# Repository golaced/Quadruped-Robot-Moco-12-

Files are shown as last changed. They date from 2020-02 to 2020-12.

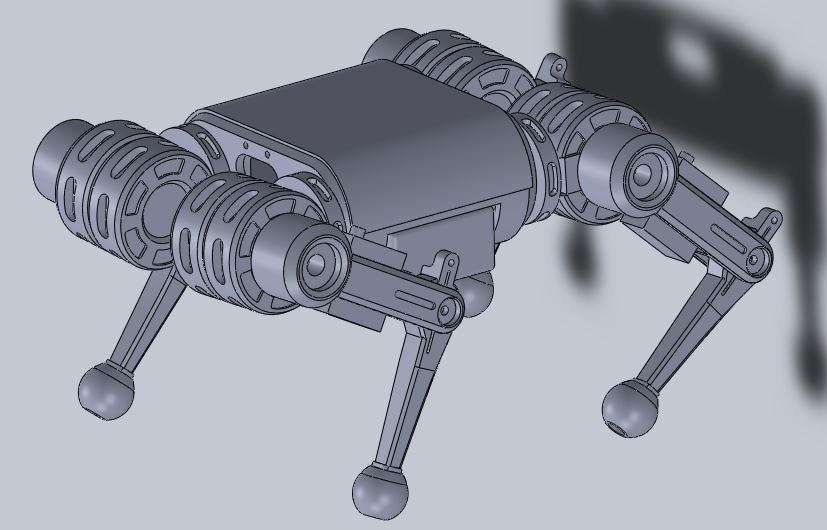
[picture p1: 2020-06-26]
教程2-主机架设计/moco-8 Test Verison/设计图/5.JPG

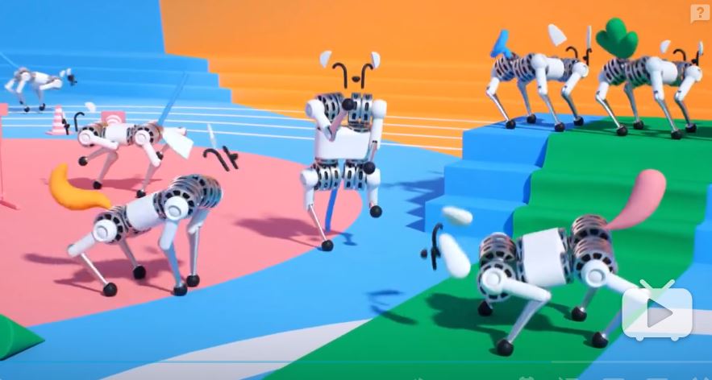
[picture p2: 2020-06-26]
教程2-主机架设计/moco-8 Test Verison/设计图/3.JPG

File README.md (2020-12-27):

# 1 Moco通用四足机器人控制器介绍  


  ____MOCO通用机器人控制器是一个面向四足、双足、六足与无人机通用的嵌入式控制器，其设计的理念是最大程度降低机器人爱好者软件开发的工作，借鉴乐高MOC构建的理念提供高性能、易用、多兼容、可快速定制的机器人/模型控制器。MOCO通用机器人控制器本质上并非一个开源飞控或机器人控制器，为提高高性能的控制效果，不同构型的机器人均采用了很多原创的算法并经过很长时间的改进，所以为保护知识产权抱歉无法为用户提供完全开源的软件代码，你可以理解为这个控制器和DJI早期NAZA飞控一样不具有完全的底层代码开发性但是配套了针对特定机器人构型所需易用的上位机能让用户快速地完成参数配置与驱动器标定，同时我们也提供丰富的二次开发接口从顶层的机器人本体位姿期望到底层的驱动器输出和关节角度均可以通过通讯协议设置，为电子开发爱好者提供一个桌面级的机器人底盘实现SLAM、人工智能和机器人视觉的开发。当然你如果对开发不感兴趣在安装完成后控制器已经能完成出色到的控制效果，你只需要关注结果设计与涂装专注于缩比模型的构建，当然它是具有高性能可动的缩比模型！<br><br>

**相关资料** <br>
机器人测试视频更新地址：https://www.bilibili.com/video/BV1Bi4y1w71m <br>
知乎相关教程：https://www.zhihu.com/column/c_1090923972006240256<br>
<br>

**-搭建该项目的方式-**

方式|说明|发货周期
-------------|-------------|-------------
整机购买(**推荐**)|从官方淘宝店购买机架+已经加工好的控制器(不包含舵机)|最长半个月
机架打印+控制器购买|自行加工项目文件免费提供的3D打印机架 +从官方购买控制器+自己购买舵机|最长1周
机架打印+控制器制版加工|自行加工3D打印机架+自行制作、焊接控制器+自己购买舵机|控制器(4层板)+IMU+下载器转接+供电模块
<br>
官方淘宝店（莲动力）：https://item.taobao.com/item.htm?spm=a1z10.1-c-s.w4004-23351273156.30.138111fbf8R4Qv&id=624417919694
<br>
<br>
**-舵机兼容-**

舵机|说明|价格
-------------|-------------|-------------
GDW9g舵机|可支持软断点|138Rmb
飞特9g总线舵机|总线控制|39Rmb
自定义|上位机配置参数| 

<br>
**-开源程序与VMC机器人库-**

方式|说明|开源模式
-------------|-------------|-------------
(**VMC机器人库**)|支持多种着地反馈、动态步态调节和更稳定的姿态控制能力，需要向官方购买授权码|闭源(目前支持STM32F4系列，且库与芯片ID绑定)
开源程序|支持基础对角步态和姿态控制|开源

<br>
**-二次开发接口-**

方式|说明|接口
-------------|-------------|-------------
Python|支持底盘、运动学等多种API|需使用USB与主控连接
C|采用串口以底盘模式提供API|树莓派等串口连接 https://github.com/golaced/MOCO_SDK
ROS|采用串口以底盘模式提供API，ROS下图像识别节点|树莓派等串口连接 https://github.com/golaced/MOCO_SDK

<br>
**-如果该项目对您有帮助请 Star 我们的项目-**<br>
**-如果您愿意分享对该项目的优化和改进请联系golaced@163.com或加入我们的QQ群567423074，加速开源项目的进度-**<br>

<br>
**-由于本人非专业研究四足机器人，该项目只是基于个人学术水平开发并不代表目前足式机器人算法就是这样，请不要过分依赖项目内容或与正规产品对比-**<br>
	
# 2 Moco-12四足机器人平台介绍

____MOCO-12 Pro是一个12自由度舵机缩比机器人模型，其原型来自于伊利诺伊大学厄巴纳大学丁博士的电驱动四足机器人，该机器人造型帅气而且体积十分小可以完全作为桌面级的机器人平台，单腿电机设计也采用了类似MIT那种三关节+连杆集成在跨关节的方式，整体机械结构的集成度十分高，原始机器人采用了MPC控制算法可以说是与MIT机器人能相媲美的一个四足机器人，我们提供的缩比模型在整体结构上较好地模仿了原型结构设计，采用连杆作为主机架，考虑舵机执行器安装对部分结构进行了修改。<br><br>

**控制器硬件参数：**

项目|参数
-------------|-------------
处理器|STM32F405RGT6
处理器性能|32Bit ARM Cortex-M4 168MH
陀螺仪 加速度计|LSM6DS33 
磁力计|LIS3MDL
气压计|MS5611
预留接口|GPS-1 串口-4 AD采样-4 着地开关输入-4
PWM 输出通道| 12通道输出 
供电|5V输入 舵机外部供电  AD传感器3.3/5V供电选择
图像处理器|树莓派A3+  1.4G 4核  带独立供电开关(控制板兼容树莓派全系列可作为外扩IO板安装，但通讯仅采用引脚串口)
遥控方式|2.4G射频 SBUS航模遥控
地面站|QGround   匿名地面站(需要额外OLDX-REMOTE监视器)

**机器人参数：**

项目|参数
-------------|-------------
足式机器人类型|8自由度并联机器人
尺寸|30cm * 20cm *10cm  
全腿长|8cm
重量|600g
供电|7.4V  18650 * 2(3000mah  续航>35 min) 带开关 
步态支持|Tort步态  Fly-Trot步态  波动步态
最大移动速度|0.4m/s
最大转向速度|30度/s
步态周期|>0.35 s
舵机性能|Kpower 12g金属舵机 *8(6V-60度/0.035s  9kg扭矩)
足底传感器|薄膜压力/微动开关(默认无传感器)
控制模式|遥控模式  姿态平衡模式(有/无着地传感器)  驾驶模式  

# 3 捐赠与项目后续开发计划
____团队计划后期推出5kg~10kg级的足式机器人开发底盘，支持RPlidar激光雷达导航进行SLAM算法验证，能以相同的价格替代目前市面上同类的四轮小车平台如Autolabor等。
 
____如果您觉得该项目对您有帮助，也为了更好的项目推进和软硬件更新，如果愿意请通过微信捐赠该项目！


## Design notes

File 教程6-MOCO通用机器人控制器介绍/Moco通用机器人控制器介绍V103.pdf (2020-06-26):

文档版本 Ver 1.04 | 修正日期 2020/6/25

# MOCO 通用机器人控制器帮助文档

# 一、MOCO 通用机器人控制器

## 1. 简介

MOCO 通用机器人控制器是一个面向四足、双足、六足与无人机通用的嵌入

式控制器，其设计的理念是最大程度降低机器人爱好者软件开发的工作，借鉴乐

高 MOC 构建的理念提供高性能、易用、多兼容、可快速定制的机器人/模型控制

器。MOCO 通用机器人控制器本质上并非一个开源飞控或机器人控制器，为提高

高性能的控制效果，不同构型的机器人均采用了很多原创的算法并经过很长时间

的改进，所以为保护知识产权抱歉无法为用户提供完全开源的软件代码，你可以

理解为这个控制器和 DJI 早期 NAZA 飞控一样不具有完全的底层代码开发性但是

配套了针对特定机器人构型所需易用的上位机能让用户快速地完成参数配置与

驱动器标定，同时我们也提供丰富的二次开发接口从顶层的机器人本体位姿期望

到底层的驱动器输出和关节角度均可以通过通讯协议设置，为电子开发爱好者提

供一个桌面级的机器人底盘实现 SLAM、人工智能和机器人视觉的开发。当然你

如果对开发不感兴趣在安装完成后控制器已经能完成出色到的控制效果，你只需

要关注结果设计与涂装专注于缩比模型的构建，当然它是具有高性能可动的缩比

模型！

## 2. 控制器硬件资源

MOCO 控制器采用 STM32 单片机作为 CPU 板载基本的陀螺仪与加速度计，

预留 12 路 PWM 输出与 4 路模拟量和开关输入，外部信号输入预留一路 SBUS 接

收机和 2 路串口，板载 5V DCDC 各 PWM 引脚供电采用外部电池输入同时具有 1

路电源使能信号输出，预留一路 USB 调试接口实现与上位机高速通讯，控制器

主板如下图所示。

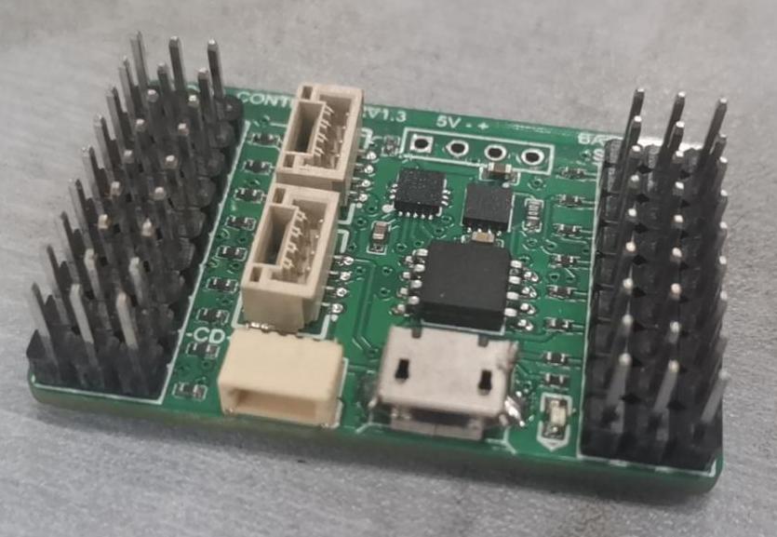
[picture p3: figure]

图 1 MOCO 通用机器人控制器（USB 端子版本）

主控尺寸小于 5*3cm 能集成到桌面级的机器人系统中，控制器各硬件资源如

下表所示：

表 1 MOCO 通用机器人硬件资源

项目 | 性能 | 备注
STM32F405RGT | 168Mhz 1K Flash | 主控芯片
LSM6DS33 | 加速度计+陀螺仪 | 6 轴姿态传感器
W25X16 | 16M-bits Flash | 参数存储芯片
AS1364-BTDT-33 | 3.3V 稳压 | 单片机降压
PWM 接口数量 | 12 个 | 外部供电
串口 | 2 路 | Uart1 Uart4
USB | 1 路 | OCU 通讯
SWD | 1 路 | 5V 供电
模拟/开关输入 | 4 路 | 3.3V 逻辑 5V 供电
SBUS | 1 路 | 5V 供电
LED | 2 个 | 状态显示
电源输入范围 | 6~20V | 5V 内部降压

连接上位机可以通过主控制器 UART1 口或者 USB 口，USB 口需要转接板，注

意！！！对于 USB 端子为卧贴的主控 4P 软线需要连接转接板的 B 面：

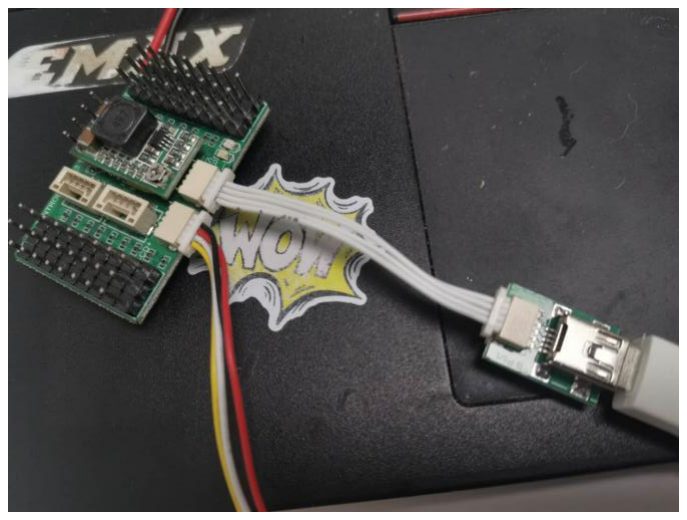
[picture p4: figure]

## 3. 控制器引脚分配

目前单片机引脚已经完全分配，后续扩展模块通过串口内部高速通讯，目前

预留的串口主要用于远程 OCU 连接、SDK 输入与遥控输入（UART1），扩展定位

模块、驱动器节点盒与传感器（UART4），单片机引脚分配如下表所示：

表 2 控制器硬件引脚分配

引脚 | 功能 | 备注
PA1 | ADC1_1 | 电池电压采集
PA4-7 | ADC1_4-7 | AD/开关量采集
PA8 | TIM1_1 | PWM9
PA9 | UART1_TX | 串口 1 发送
PA10 | UART1_RX | 串口 1 接收
PA11 | DM | USB- PA12 | DP | USB+
PA13 | SWD | 下载器
PA14 | SCK | 下载器
PB0 | TIM3_3 | PWM3
PB1 | TIM3_4 | PWM4
PB4 | TIM3_1 | PWM1
PB5 | TIM3_2 | PWM2
PB6 | TIM4_1 | PWM5

PB7 | TIM4_2 | PWM6
PB10 | TIM2_3 | PWM7
PB11 | TIM2_4 | PWM8
PB12 | | LED_R
PB13 | SPI2_SCK
PB14 | SPI2_SO
PB15 | SPI2_SI
PC0 | | LED_G
PC4 | | SPI2_IMU 片选
PC5 | | SPI2_FLASH 片选
PC6 | TIM8_1 | PWM10
PC7 | TIM8_2 | PWM11
PC8 | TIM8_3 | PWM12
PC9 | | 电源开关信号 3.3V
PC10 | UART4_TX | 串口 4 发送
PC11 | UART4_RX | 串口 4 接收
PD2 | UART5_RX | 反向/SBUS 接收

## 4. 控制器端子说明

主控端子均朝向上方采用典型飞控的引脚分配使用 2.54 排针作为主伺服控

制信号的输出，SWD 与 USB 均采用 1.25 端子引出方便不调试时去除连线，USB

调试口配套对应连接转换板方便控制器内置时的参数调节，动力主供电通过 PCB

右上角焊盘或供电线引出，主控控制电通过 PWM 排针输入同时输出 1 路开关信

号给外部继电器或电源控制器实现对动力电的关闭和开启，4 路模拟量/开关信

号输入能作为四足机器人足底传感器或开关传感器的输入，SBUS 接受引脚实现

对航模遥控器信号的采集，具体端子分布如下图所示。

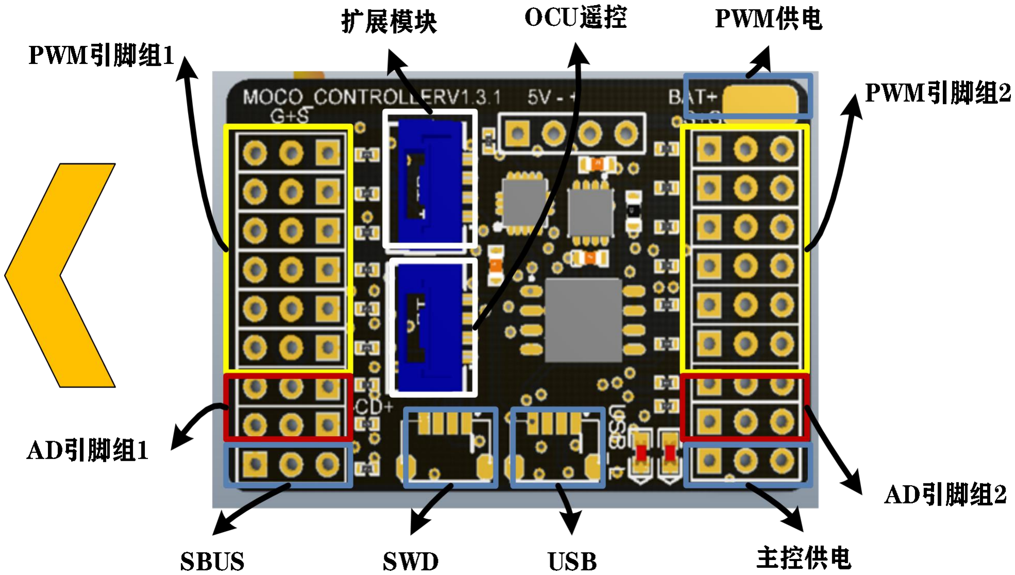
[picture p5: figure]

图 2 控制器端子示意图（《箭头为机头方向）

如上图所示，PWM 供电焊盘上面为 VCC+背面为 GND（最大输入 24V）LF 左

前，RF 右前，LH 左后，RH 右后。

PWM 引脚组 1 一侧对应的引脚说明如下：

从上到下 | 功能 | | 从左到右
PWM6 | RF 腿小腿 | GND | VBAT | Signal
PWM5 | RF 腿大腿 | GND | VBAT | Signal
PWM2 | RF 腿侧摆 | GND | VBAT | Signal
PWM1 | LF 腿侧摆 | GND | VBAT | Signal
PWM11 | LF 腿大腿 | GND | VBAT | Signal
PWM12 | LF 腿小腿 | GND | VBAT | Signal
GROUND2 | RF 腿足底采集 | GND | 5V | Signal
GROUND1 | LF 腿足底采集 | GND | 5V | Signal
SBUS | 遥控输入 | GND | 5V | Signal

如上图所示，PWM 引脚组 2 一侧对应的引脚说明如下：

从上到下 | 功能 | | 从左到右
PWM3 | RH 腿小腿 | Signal | VBAT | GND
PWM4 | RH 腿大腿 | Signal | VBAT | GND

PWM7 | RH 腿侧摆 | Signal | VBAT | GND
PWM8 | LH 腿侧摆 | Signal | VBAT | GND
PWM10 | LH 腿大腿 | Signal | VBAT | GND
PWM9 | LH 腿小腿 | Signal | VBAT | GND
GROUND3 | RH 腿足底采集 | Signal | 5V | GND
GROUND4 | LH 腿足底采集 | Signal | 5V | GND
POWER | 控制电输入 | 电源开关 | VBAT | GND

如上图所示，SWD 引脚组对应的说明如下：

功能 | 从左到右
SWD | GND | SCK | SWD | 5V

如上图所示，USB 引脚组对应的说明如下：

功能 | 从左到右
USB | 5V | DM | DP | GND

如上图所示，扩展模块引脚组对应的说明如下：

功能 | 从上到下
UART4 | RX
| TX
| GND
| 5V

如上图所示，OCU 遥控引脚组对应的说明如下：

功能 | 从上到下
UART1 | TX
| RX
| GND
| 5V

## 5. 控制器使用电气连接

控制器电气连接主要完成 PWM 与舵机或无刷电机驱动器的连接，PWM 供电

线与电池的连接，主控供电线与电池的连接，遥控器的连接，USB 与上位机的连

接，外扩模块与串口的连接，则具体连线示意图如下所示。

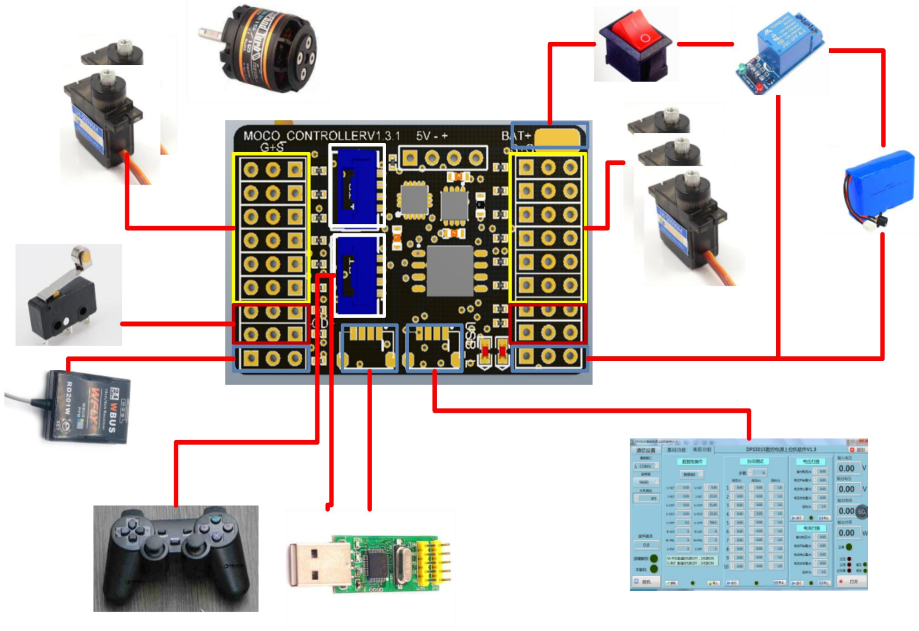
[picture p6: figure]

图 3 控制器电气连接

如上图所示，PWM 接口可以直接连接舵机驱动或者连接电子调速器驱动无

刷电机，AD 接口可以连接微动开关采集足底开关信息，OCU 端子可以选择连接

无线遥控器接收器或者直接连接 SWD/TTL 转串口一体模块，USB 端口则连接

OCU，上述遥控输入 SBUS 优先级高于串口、串口高于 OCU。供电端电池同时给

板子 DCDC 与 PWM 引脚供电，供电口输出的开关信号可以用于控制继电器开关

动力电源，同时也可以增加一个主动开关。

注意：控制器默认 PWM 供电与控制电是分开的，所有到手直接连接 PWM

的 JST 供电口控制器是不会上电的，因此需要从外部引入一路电池到供电引脚

（注意千万不要插错），或者直接从主控 PWM 供电+极焊盘引出一路电源到主

控供电引脚！！！！！

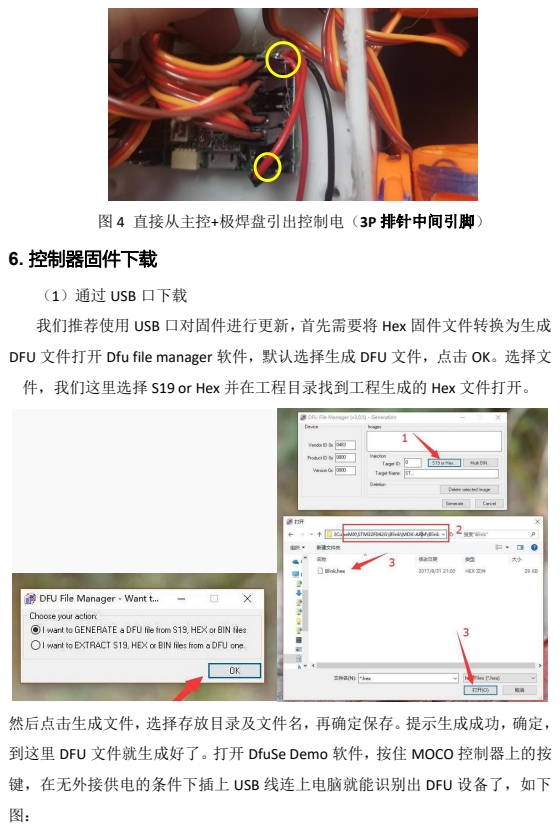
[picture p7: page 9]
6. 控制器固件下载

图 4 直接从主控+极焊盘引出控制电（3P 排针中间引脚）

（1）通过 USB 口下载

我们推荐使用 USB 口对固件进行更新，首先需要将 Hex 固件文件转换为生成
DFU 文件打开 Dfu file manager 软件，默认选择生成 DFU 文件，点击 OK。选择文

件，我们这里选择 S19 or Hex 并在工程目录找到工程生成的 Hex 文件打开。

然后点击生成文件，选择存放目录及文件名，再确定保存。提示生成成功，确定，
到这里 DFU 文件就生成好了。打开 DfuSe Demo 软件，按住 MOCO 控制器上的按

键，在无外接供电的条件下插上 USB 线连上电脑就能识别出 DFU 设备了，如下

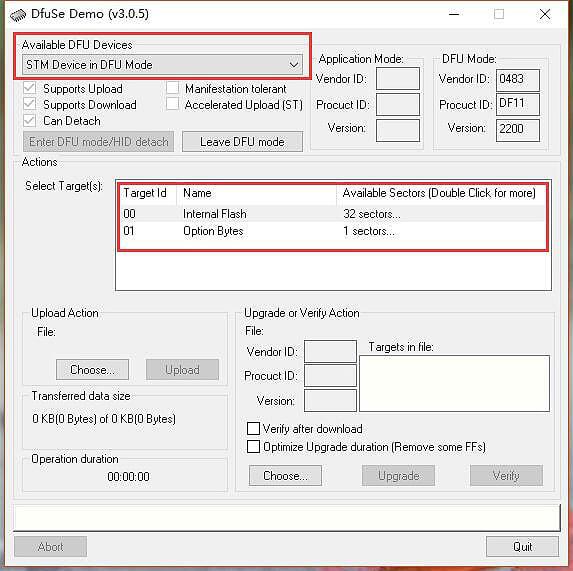
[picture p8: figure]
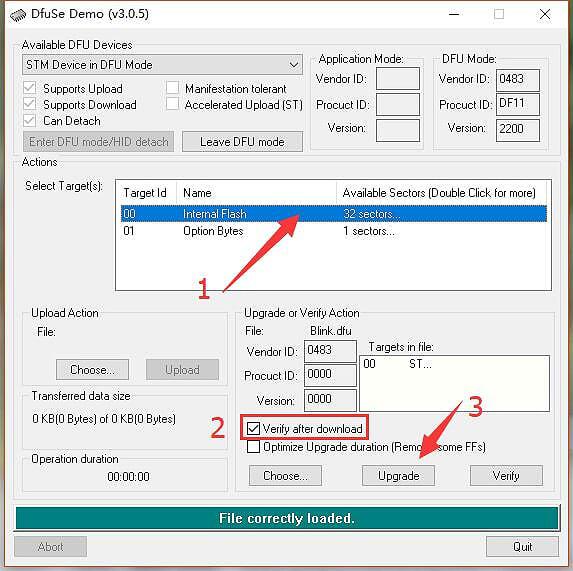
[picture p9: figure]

选择文件，在弹出窗口中找到之前软件生成的 DFU 文件或者下载的 DFU 文件，

## 选择并打开。双击 Target Id 中的 STM32 Flash 一栏，点击 Choose 选择刚才生成

到的 Dfu 文件后，点击 Upgrade 进行下载，当读条完毕无错误报出则可以连接

OCU 上位机查看固件版本。

（2）通过 SWD 口下载

目前控制器固件需要通过 STlink 下载，首先使用转接线与 STlink 的 SWD 接口

对接并从下载口提供 5V 供电，之后使用 STM32 ST-LINK Utility 下载固件。首先

连接单片机 ，正确连接后显示：

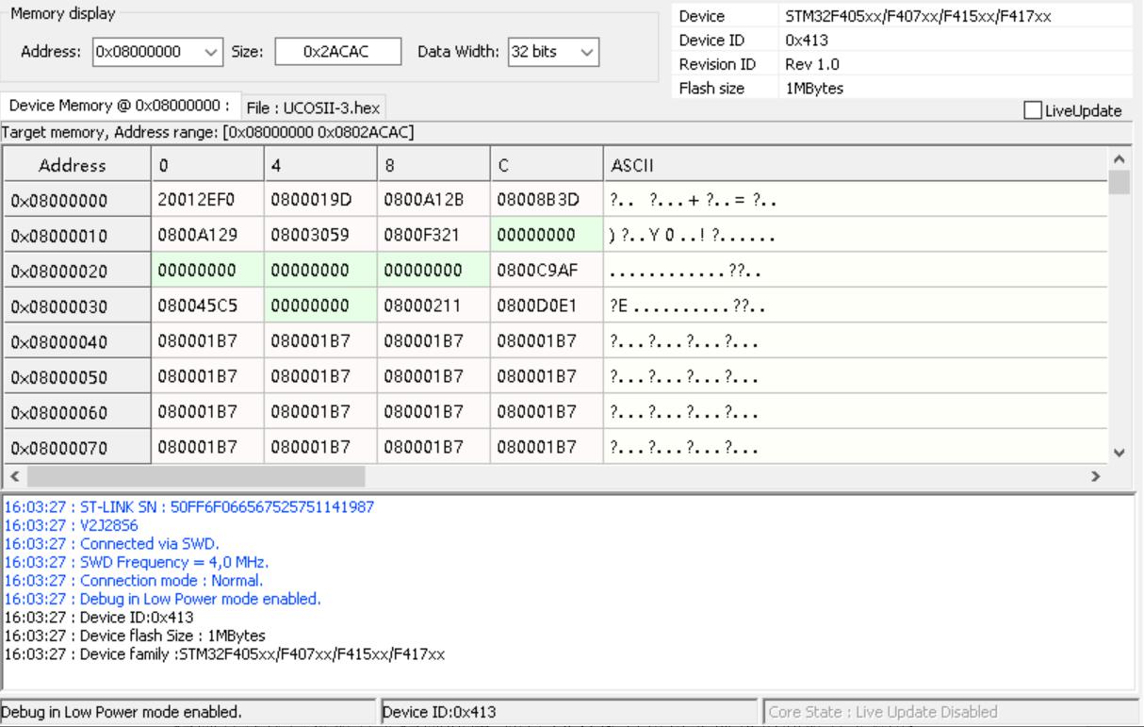
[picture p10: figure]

之后选择需要下载的固件，点击 File 选择 Open File 功能，找到 Moco.hex 固件确

认：

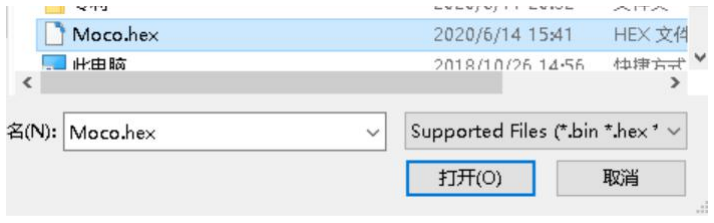
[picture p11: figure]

## 选择 Target 点击 Program and Vertify 下载固件：

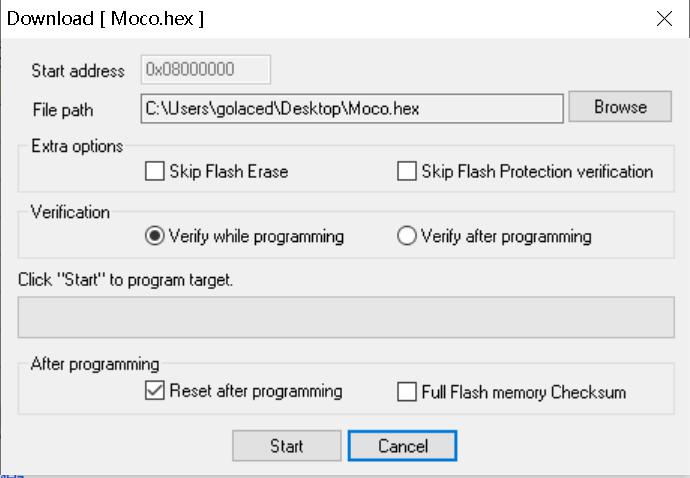
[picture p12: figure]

点击 Start 开始下载当读条完毕，并显示如下说明则固件下载完成：

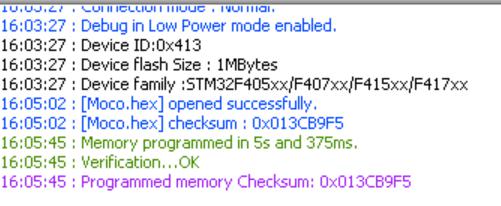
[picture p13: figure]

（3）V1.3 硬件版本 USB 固件下载示意

在 V1.3 版本硬件中没用增加 Boot 引脚上拉接口，因此可能无法直接使用 USB

下载固件，为方便后续调试我们推荐有能力的开发者自行在电路板对应电阻焊接

一个杜邦线方便上拉下载固件：

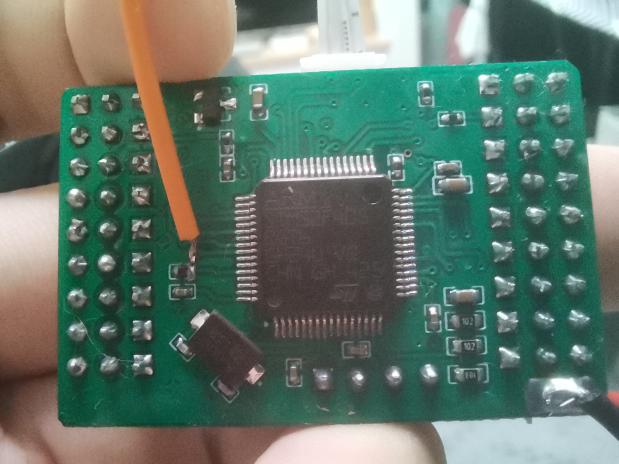
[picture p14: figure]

如上图所示用户需要在控制器背面晶振上方电阻的内测焊盘点上一根杜邦

线，注意不要焊接错误！！

则当需要烧写固件时将其插在排针输出中任意 5V 输出位置，注意不要插在

12 路 PWM 的供电引脚因为其为电池电压高于 5V，我们推荐插在下图位置并且

下载固件时只使用 USB 供电：

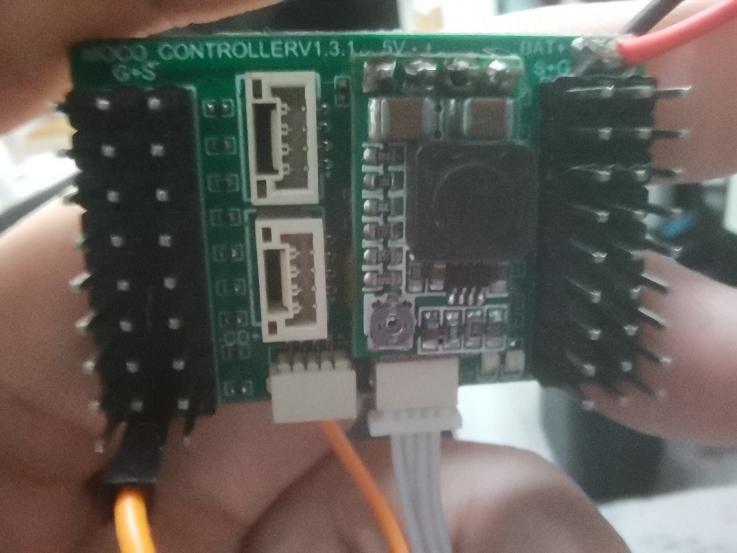
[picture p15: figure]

则当连接正确后将 USB 与转接模块连接，注意电路板 USB 4P 端子与目前转

接板的 B 面连接：

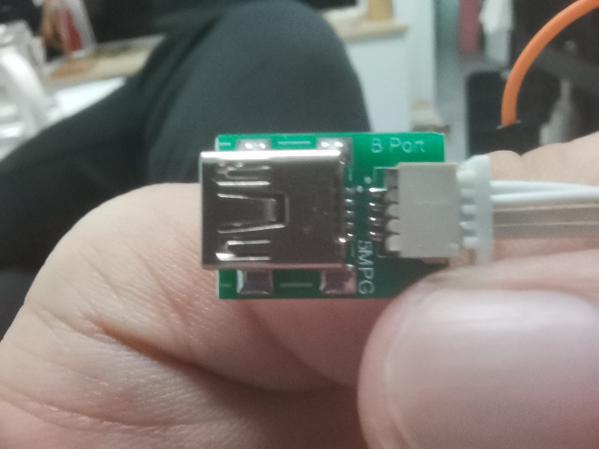
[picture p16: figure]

## 7. 控制器使用与授权

控制器默认烧录机器人控制固件，通过 OCU 配置可以完成对不同机器人构型

的选择和参数的调节，另外用户也可以自己通过 SWD 烧录程序将其作为一个

STM32F4 单片机开发板使用，为保护自主知识产权控制器仍然采用 OLDX 飞控软

件授权的方式，即 MOCO 机器人控制固件仅与官方加工的硬件绑定的方式实现，

用户使用软件需要提供 OCU 上显示的芯片 ID 并获取授权码（在上位机参数界面

写入并保存）。

当然我们也提供面向任意同系列单片机和开发板的通用固件，其相关步态功

能和机器人参数会受到限制，具体说明请查看《上位机帮助使用说明文档》。

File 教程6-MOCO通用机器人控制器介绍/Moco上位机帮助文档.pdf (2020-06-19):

文档版本 Ver 1.0 | 修正日期 2020/6/1

# MOCO 通用机器人 OCU 帮助文档

# 一、MOCO 通用 OCU 上位机

## 1. 简介

MOCO 通用 OCU 上位机是支持 MOCO 机器人控制器进行快速配置与参数调

节的跨平台软件，其基于 Python 内核能部署于 Windows 与 Ubuntu 系统。上位

机支持对机器人构型的选择可以快速完成 MOCO 系列四足机器人的建立，同时

还支持用户基于机器人构型参数快速自定义，同时上位机集成参数在线调节功能

能快速实现参数的整定并配有波形显示为姿态控制参数整定提供可视化指标。为

方便用户测试上位机提供了对舵机输出的标定界面用户能快速完成角度偏差标

定与转向标定，同时提供完善的测试步骤在机器人标定配置完成后用户依据测试

流程既可以完成对机器人稳定性的快速调试，为实现参数保存上位机也支持对配

置参数的本地存储与快速写入，相比上一代代码调节的方式大大加快机器人的调

试！

备注：环境配置，将“MOCO_OCU 图片”文件夹复制到 D:/根目录下

## 2. OCU 上位机功能介绍

OCU 上位机主要分为主界面、机器人向导、参数设置、执行器标定、传感器

标定、测试模式与控制模式几大界面，连接上位机可以通过主控制器 UART1 口

或者 USB 口，USB 口需要转接板，注意！！！对于 USB 端子为卧贴的主控 4P 软线

需要连接转接板的 B 面：


各界面主要功能如下：

（1）主界面：

该界面主要完成机器人状态的显示，包括姿态、位置、速度、控制模式等，

同时以图像的模式显示各关键角度，同时可以在主界面完成串口配置以及对波形

曲线的查看。

（2）机器人向导：

该界面主要完成对机器人快速的向导式配置，可以选择 Moco 系列机器人实

现对官方特定构型机器人参数的配置和下载，另外也可以通过 DIY 模式依据用户

自己的机器人参数进行设置。

（3）参数配置界面：

该界面主要对机器人内部参数的在线整定和保存，可以完成对机器人典型位

姿控制增益，落足、姿态偏差的调节，也可以实现对参数的快速恢复出厂设置。

（3）执行器标定界面：

该界面主要完成对 12 路 PWM 输出的快速标定，包括各 PWM 输出的偏差以

及执行器旋转的方向，同时也可以完成对舵机时间参数的标定让用户使用自己的

舵机数据。

（4）传感器标定界面：

该界面主要完成对板载 IMU 的标定包括对其测量偏差和尺度偏差，对磁场的

在线拟合标定以及 GPS 和 IMU 安装位置角度的标定。

（5）测试模式界面：

该界面主要完成在机器人配置完成后对各独立功能的快速测试来验证参数

配置的正确性，包括正逆运动学、伪逆力控和位姿调节等。

（6）控制模式界面：

该界面主要为用户提供一个在无遥控器下快速测试机器人的方法，可以实际

基于按键与键盘操作下机器人速度、姿态和步态的快速调节。

## 3. 状态主界面介绍

该界面主要完成机器人状态的显示，包括姿态、位置、速度、控制模式等，

同时以图像的模式显示各关键角度，同时可以在主界面完成串口配置以及对波形

曲线的查看，具体功能如下：

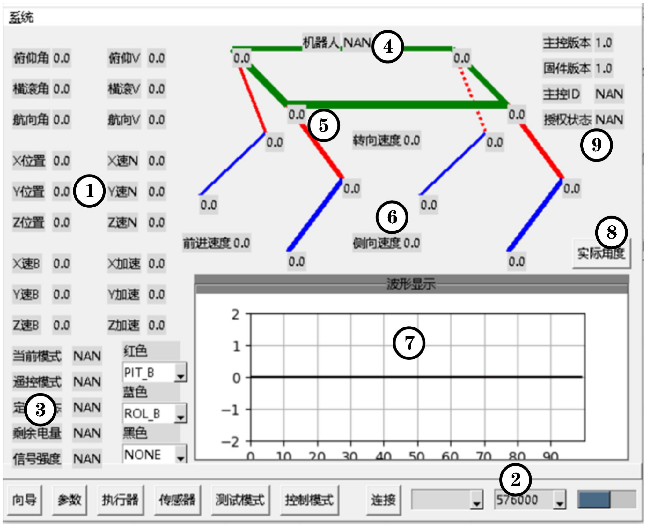
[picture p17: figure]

图 1 状态主界面

上图中各标号对应功能如下：

①机器人状态显示栏：完成对机器人姿态角、角速度、加速度、位置、速度

的显示；

②串口设置：系统连接后默认搜索串口，也可以点击下拉栏选择 COM 口和

波特率，当串口连接后右侧数据条会不断走动，如串口通信故障请查看控制台打

印信息并查看后文故障处理说明章节；

③模式显示栏：完成对机器人状态的显示，其中当前模式显示机器人步态状

态如下:

状态 | 遥控切换操作 | 功能
离线 | 无 | 机器人未连接 OCU
安全 | 遥控下 | 关闭动力电源
站立 IMU/RC | 遥控左->TROT

## 遥控右->WALK

| | IMU 站立模式
TROT | 遥控上->FROT

## 遥控右->WALK

| | 普通对角步态

遥控上->站立 IMU
FTROT | 遥控左->TROT
| 遥控上->站立 IMU

飞行相对角步态

WALK | 遥控左->TROT
| 遥控上->站立 IMU

爬行步态

自恢复 | 摔倒+遥控右 | 摔倒自恢复模式（恢复完
| | 成后采用站立切换方式重
| | 新移动）

遥控状态对应介绍如下：

状态 | 遥控切换操作 | 功能
手动-遥 | 无 | 使用遥控器手动操作
手动-键 | 无 | 使用键盘手动操作
自动 | 遥控打断，无遥控自动恢复

④机器人信息：显示连接机器人构型的信息，具体官方 Moco 系列机器人构

型如下表所示：

机器人 | 构型 | 说明
Moco 8-Pro | 8 自由度
| 并联腿 | 官方原创造型
Moco 8-Cheetha | 8 自由度
| 串联腿 | 造型仿 MIT
| | Mini-Cheetha
Moco 8-LS3 | 8 自由度
| 并联腿 | 造型仿波士顿动力 LS3
Moco 8-Mid | 8 自由度
| 并联腿 | 造型仿 GhostRobotic
| | Miniature
Moco 12-Pro | 12 自由度 | 造型仿丁博士四足

串联腿 | 机器人
Moco 12-LS3 | 12 自由度

串联腿

造型仿波士顿动力
LS3

⑤机器人角度显示：以图像化方式显示对应关节角度和期望角度可以通过⑧

按键进行快速切换，具体各角度对应关系请查看相应机器人构型安装文档；

⑥遥控命令显示：完成对遥控产生期望前后速度、转向速度的显示，其中前

后速度单位为 m/s，转向角度单位为度/s；

⑦波形显示：完成对机器人内部角度、速度等波形的显示，三通道显示数据

内容可以在左侧下拉菜单处选择；

⑨控制器固件与授权状态：显示控制器固件版本以及授权所需要控制器芯片

ID 编号，授权方法请查看控制器使用说明；

## 4. 机器人向导界面介绍

该界面主要完成对机器人快速的向导式配置，可以选择 Moco 系列机器人实

现对官方特定构型机器人参数的配置和下载，另外也可以通过 DIY 模式依据用户

自己的机器人参数进行设置，如下图所示

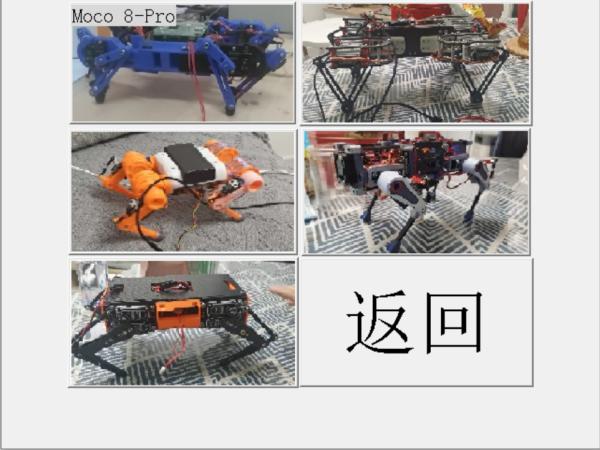
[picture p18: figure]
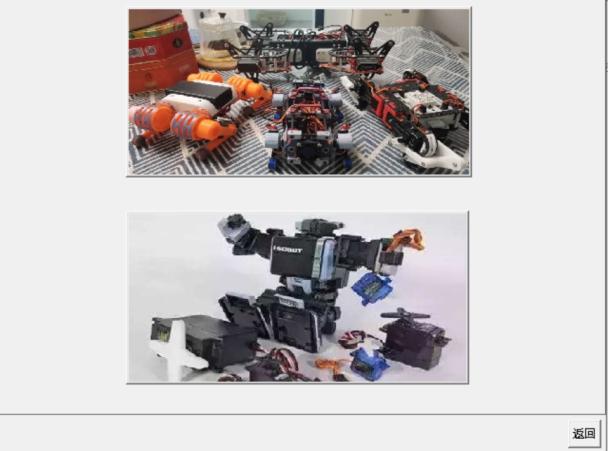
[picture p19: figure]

图 2 Moco 系列与 DIY 机器人配置界面

## 4.1 Moco 系列机器人向导

该向导面向官方推出的 Moco 系列机器人，用户可以在该界面快速完成对机

器人相关参数的配置，当然机器人构型已经确定，用户主要可以完成对相关辅助

功能如摔倒保护、步态切换的配置，最重要的是完成对控制器授权码的写入，以

## Moco 12-Pro 为例其界面如下所示：

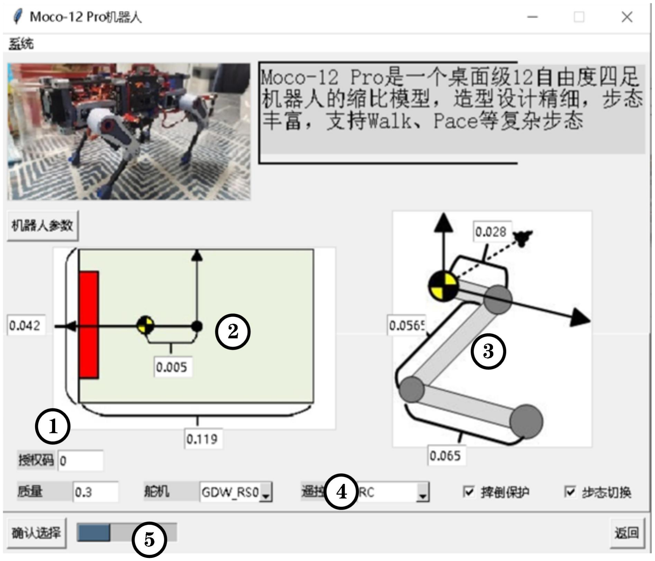
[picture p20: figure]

图 3 Moco 系列机器人向导

①授权码写入：将芯片 ID 对应的授权码写入该处；

②机器人机体参数：可以对机器人机体参数进行修改，对于采用官方套件的

用户可以不用修改；

③腿部参数修改：可以对机器人单腿参数进行修改，对于采用官方套件的用

户可以不用修改；

④辅助功能修改：可以完成对机器人质量、舵机型号和辅助功能的修改；

⑤配置确认：点击后会出现读条，当提示写入成功后切换到测试界面；

## 4.2 自定义机器人向导

该向导面向用户自定义机器人，用户可以在该界面快速完成对机器人相关参

数的配置，完成对腿部构型、结构尺寸以及相关辅助功能的配置，该功能在开放

中！

## 5. 参数配置界面介绍

该界面主要对机器人内部参数的在线整定和保存，可以完成对机器人典型位

姿控制增益，落足、姿态偏差的调节，也可以实现对参数的快速恢复出厂设置，

具体界面如下：

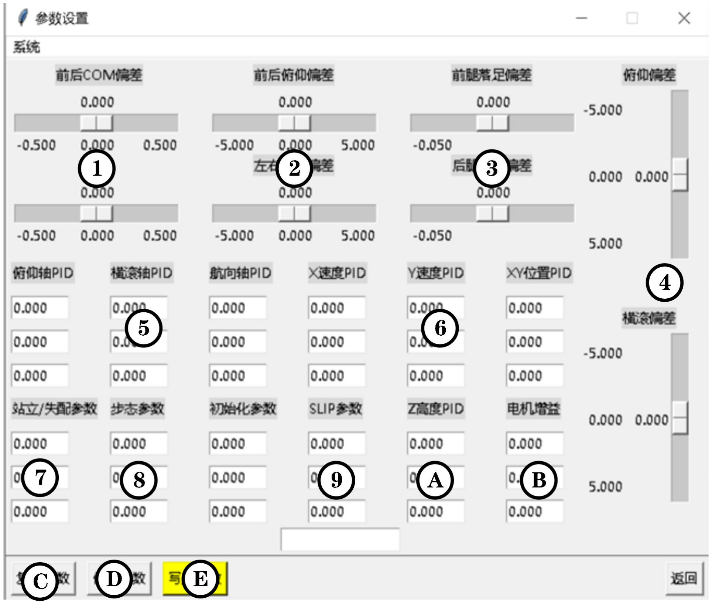
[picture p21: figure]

图 4 参数配置界面

①前后 COM 偏差：该参数为机器人前后移动时机器人整体落足的偏差，上方为

前进参数，下方为后退参数，参数为正时落足偏向机体方向；

②前后俯仰、左右横滚偏差：该参数为机器人移动时姿态规划角度，其中俯仰偏

差决定前后移动时俯仰角度，参数为正时机器人抬头，同理横滚参数决定机器人

侧向移动与转向时的角度；

③前后腿落足偏差：该参数为机器人前后腿 X 方向固定落足偏差，如机器人移动

时出现栽头或后坐需增加该偏差；

④俯仰横滚偏差：该参数为姿态控制中固定角度偏差，其用于补充陀螺仪标定误

差与机器人配重不均引起的移动不稳定；

⑤姿态控制参数：机器人姿态控制虚拟伺服的 PID 参数，从上往下为 P、I 和 D；

⑥XY 方向力控参数：该参数为前向和侧向虚拟伺服机器人力控 PID 参数；

⑦站立失配参数：该参数前两个为机器人站立时足底 XY 方向复位力控参数，第

三行参数为落足失配参数，其为对角腿中心连线误差控制参数，该增益保证步态

运行中对角腿连线高度，如移动中出现沿对角线晃动需调节此参数；

⑧步态参数：该参数为步态控制器核心参数，第一行为步态周期，第二行为摆动

高度，第三行为倒立摆控制模型中速度反馈控制增益系数；

⑨SLIP 参数：该参数为 FTROT 时使用的 SLIP 模型参数，其中第一行为力控反馈 P

系数，第二行为重力前馈系数，第三行为高度弹跳幅度系数，如机器人无法挑起

则需要增大该系数；

A 高度控制系数：该参数为高度虚拟伺服 PID 参数；

B 电机增益系数：该参数为电机模型系数，其中第一行对应扭矩输出，第三行对

应电机时间常数；

C 复位按键：该按键为参数初始化按键，点击后控制器复位默认控制参数；

D 使能按键：该按键单次点击后下方当前界面参数；

E 写入按键：该按键完成控制器参数向 FLASH 的保存；

## 6. 执行器标定界面介绍

该界面主要完成对 12 路 PWM 输出的快速标定，包括各 PWM 输出的偏差以

及执行器旋转的方向，同时也可以完成对舵机时间参数的标定让用户使用自己的

舵机数据，界面介绍如下：

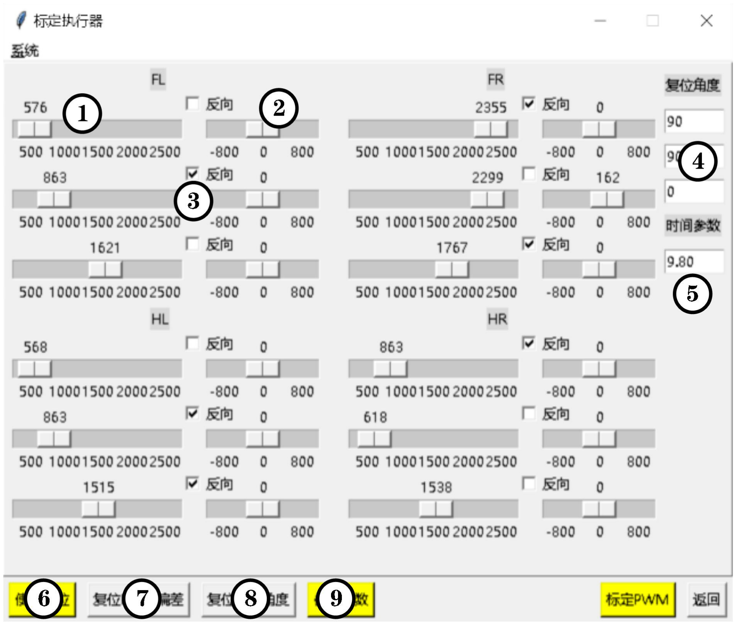
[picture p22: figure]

图 5 执行器标定界面

①PWM 输出值显示：该指示显示当前控制器对应口输出的 PWM 值，其中第一

行为侧摆、第二行为大腿、第三行为小腿，FL 为左前腿，FR 为右前腿；

②舵机偏差：拖动该条能调节对应通道舵机的偏差；

③舵机旋转角度：该选项完成对舵机旋转角度的选择，通过选择该选项保证角度

与机器人构型旋转角度和坐标系方向一致；

④复位角度：该角度为单腿当前复位角度，其中第一行为小腿，第二行为大腿，

第三行为侧摆；

⑤舵机时间参数：该参数为舵机 PWM 值与角度的对应关系，进入该界面后会读

取底层值用户可以认为修改，设定复位角度为 90°并与机器人构型对比旋转固

定角度进行手动调节，当然我们已经提供目前市面上大多数舵机对应的参数；

⑥使能复位按键：点击后控制器会输出 PWM 值控制电机到设定复位角度；

⑦复位偏差：点击后所有通道 PWM 偏差复位为 0；

⑧角度复位：点击后复位角度设置到 90、90、0 度；

⑨保存参数：点击后将当前参数写入 FLASH；

## 7. 传感器标定界面介绍

该界面主要完成对板载 IMU 的标定包括对其测量偏差和尺度偏差，对磁场的

在线拟合标定以及 GPS 和 IMU 安装位置角度的标定，具体介绍如下：

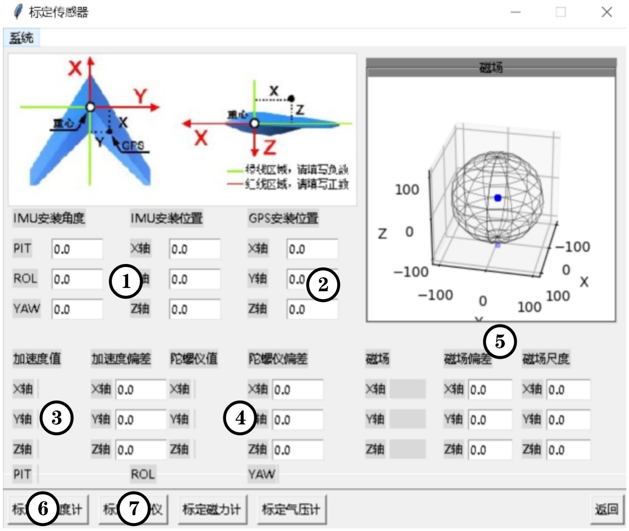
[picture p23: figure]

图 6 IMU 标定界面

①IMU 安装参数：设置 IMU 安装的角度和位置（如控制机头安装方向有偏角可

以设置 z 轴角度，顺时针转动角度为+）；

②GPS 安装参数：设置 GPS 安装位置，目前无用；

③加速度值：当前加速度测量值，单位为 g，右侧为当前控制器读出标定偏差；

④陀螺仪值：当前陀螺仪测量值，单位为度/s，右侧为当前控制器读出标定偏差；

⑤磁场标定：当前标定的磁场数据，目前无用；

⑥标定加速度：点击后以当前机器人角度为 0 标定加速度；

⑦标定陀螺仪：点击后以当前角速度读数标定陀螺仪；

注：上述参数均可写入配置文件中！

## 8. 测试模式界面介绍

该界面主要完成在机器人配置完成后对各独立功能的快速测试来验证参数

配置的正确性，包括正逆运动学、伪逆力控和位姿调节等，各测试项目如下图所

示：

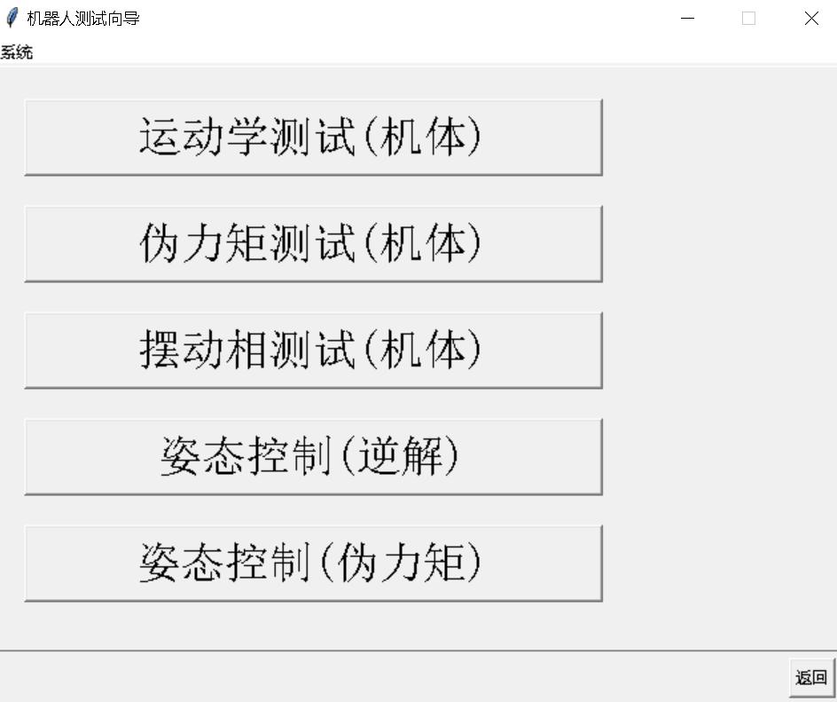
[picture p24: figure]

图 7 测试界面选项

## 8.1 运动学测试界面

该界面用于测试机器人运动学正逆解是否正确，可以实时显示机器人各关节

角度以及末端正解 XYZ 坐标，同时可以通过拖动滑条调节期望的末端位置，则具

体界面功能如下：

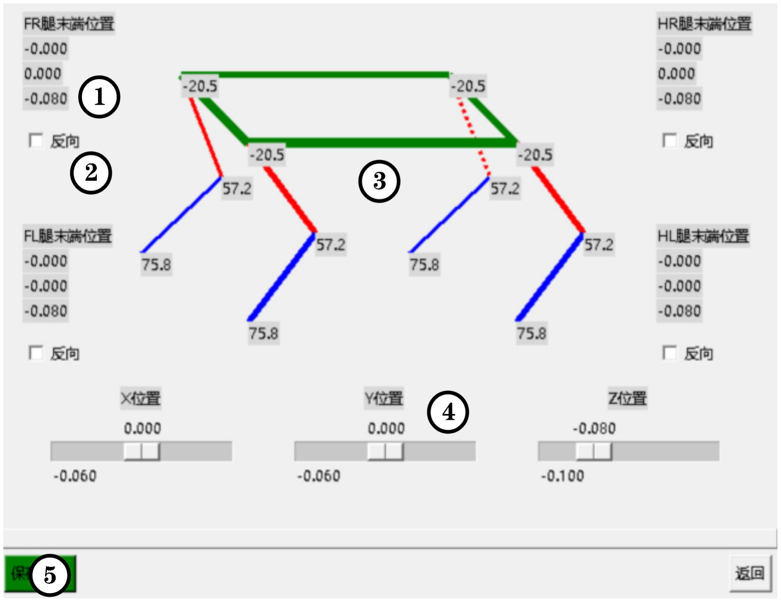
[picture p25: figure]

图 8 运动学测试

①末端正解位置：显示控制器底层解算的末端位置

②正反膝设置：选择该腿是内肘还是外肘，默认不选择反向为如上图所示的

构型；

③关节角度：显示控制器底层逆解设定位置得到的关键角度；

④设定末端位置：设定的跨坐标系下末端位置默认前方为 X 正方向、右侧为

Y 轴正方向、上为 Z 轴正方向；

⑤保存：点击保存腿部内外肘配置参数；

## 8.2 伪力矩测试界面

该界面用于测试机器人伪力控是否正确，可以实时显示机器人各关节角度以

及末端正解 XYZ 坐标，同时可以通过拖动滑条调节期望的末端伪力，则具体界面

功能如下：

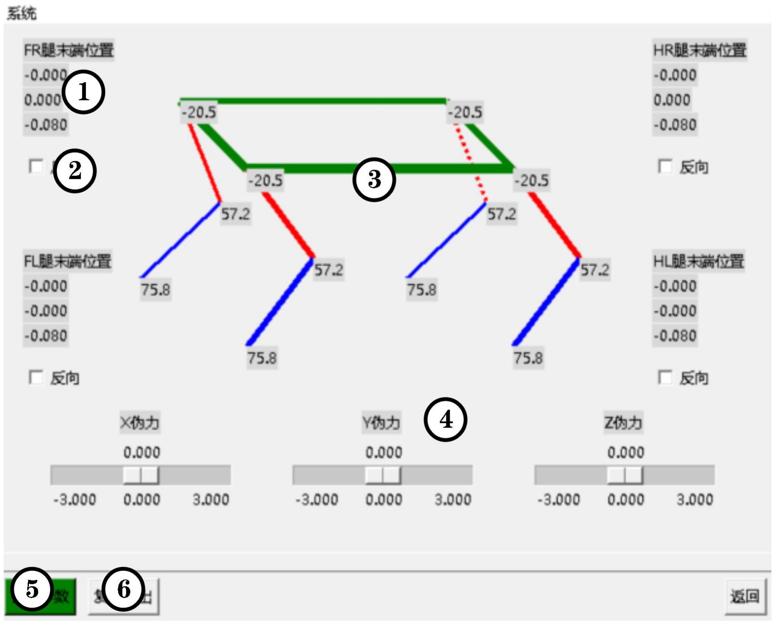
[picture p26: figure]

图 9 伪力测试

①末端正解位置：显示控制器底层解算的末端位置

②正反膝设置：选择该腿是内肘还是外肘，默认不选择反向为如上图所示的

构型；

③关节角度：显示控制器底层逆解设定位置得到的关键角度；

④设定末端伪力：设定的全局坐标系下末端伪力，默认前方为 X 正方向、右

侧为 Y 轴正方向、上为 Z 轴正方向；

⑤保存：点击保存腿部内外肘配置参数；

⑥复位：复位各轴伪力期望为 0

注：该测试函数为全局坐标系下的伪力，因此坐标系为全局坐标系，姿态变

化会引起末端移动方向的不同；

## 8.3 摆动相测试界面

该界面用于测试机器人摆动相是否正确，可以实时显示机器人各关节角度以

及末端正解 XYZ 坐标，同时可以通过拖动滑条调节期望的末端落足位置和摆动参

数，则具体界面功能如下：


图 10 摆动测试

①末端正解位置：显示控制器底层解算的末端位置

②正反膝设置：选择该腿是内肘还是外肘，默认不选择反向为如上图所示的

构型；

③关节角度：显示控制器底层逆解设定位置得到的关键角度；

④设定摆动：设定的全局坐标系下摆动落足点和摆动高度，默认前方为 X 正

方向、右侧为 Y 轴正方向、上为 Z 轴正方向；

⑤保存：点击保存腿部内外肘配置参数；

⑥复位：复位摆动落足点；

注：该测试函数为全局坐标系下的落足点，因此坐标系为全局坐标系，姿态

变化会引起落足位置的不同；

## 8.4 姿态控制（运动学）界面

该界面实现机器人基于运动学和逆解的姿态稳定，可以实时显示机器人各关

节角度以及末端正解 XYZ 坐标，同时可以通过拖动滑条调节期望机体参数和角度

的设置，同时有三种模式验证运动学的正确性，则具体界面功能如下：


图 11 运动学姿态控制测试

①XY 方向外扩：调节各腿对称的外扩偏差，外扩越大机器人稳定性越好；

②位姿参数：实时显示机器人姿态和位置数据；

③关节角度：显示控制器底层逆解设定位置得到的关键角度；

④电机参数：设定电机的增益与时间参数，其中电机增益可以当做不同尺寸

机器人的总增益进行调节；

⑤测试模型：选择不同的测试模式：

模式 | 功能
遥控模式 | 该模式实现运动学的遥控角度设置， 机器人姿态接受 OCU 设定角度，基于
| 该模式可以实现机器人 6 轴位姿扭动
| 测试；
平衡模式 | 该模式在上一模式基础上引入IMU反
| 馈，可以实现在平台倾角变化下的姿
| 态平衡；

随动模式 | 该模式可以实现机器人姿态跟随外
| 力；

⑥位置设置：设置质心期望的全局位姿；

⑦角度设置：设置期望的姿态角度；

## 8.5 姿态控制（伪力控）界面

该界面实现机器人基于伪力控在全局姿态下的位姿控制，可以实时显示机器

人各关节角度以及末端正解 XYZ 坐标，同时可以通过拖动滑条调节期望机体参数

和角度的设置，界面提供了位姿控制所需要的主要参数都进行在线整定的功能，

则具体界面功能如下：


图 12 伪力控姿态测试

①俯仰横滚偏差：顶层伺服姿态控制的固定偏差用于补充 IMU 标定误差和配

重不均匀；

②位姿参数：实时显示机器人姿态和位置数据；

③期望角度和高度：设定机器人期望质心高度与角度；

④位姿参数：用于整定机器人姿态和高度伪力控的 PID 参数；

⑤电机设置：用于设置电机参数；

## 9. OCU 控制界面介绍

该界面主要为用户提供一个在无遥控器下快速测试机器人的方法，可以实际

基于按键与键盘操作下机器人速度、姿态和步态的快速调节，该界面与北通或支

持 PS2 的遥控器一致，按键完全复刻其布局，因此遥控操作也与插入遥控器的方

法一样，只不过将遥杆分解为对应的拖动滑条，并增加复位按键方便快速复位。


图 13 北通遥控器

上图中各按键功能布局如下所述：

①模式切换按键：实现对机器人模式的切换，详情参看前文控制模式说明；

②扩展模式按键：详情参看前文控制模式说明；

③速度遥控遥杆：控制机器人前后左右速度；

④姿态遥控遥杆：控制机器人俯仰横滚姿态；

⑤高度控制按键：实现对机器人高度的调节；

⑥转向控制按键：实现对机器人转向速度控制；


图 14 上位机遥控界面

上图中各按键功能布局如下所述：

①前后控制拖动条：对应遥控器左遥杆前后方向，即机器人前后移动速度控

制；

②转向控制拖动条：对应遥控器左上右上行程按键，即机器人转向移动速度

控制；

③左右控制拖动条：对应遥控器左遥杆左右方向，即机器人左右移动速度控

制；

④姿态控制拖动条：对应遥控器右遥杆，左拖动条对应上下控制机器人俯仰

角，右拖动条对应遥杆左右控制机器人横滚角；

⑤复位按键：实现对各拖动条快速复位，另外也能通过强制保护实现一键断

电（当然遥控器模式中按键 Down 直接对应 Safety 模式）；

## 10.控制器标定教程

控制器标定主要完成机器人构型选择，授权码输入，参数调节和移动测试几

个步骤，下面给出 Moco 机器人系列标定控制器的简单教程:

（1）选择机器人：

进入机器人向导界面选择对应的机器人型号，在授权码中写入主界面显示芯

片 ID 对应的授权码，在向导中选择辅助选项之后点击新建机器人。

注：对于用户自行 DIY 的机器人如构型与单腿设计与 Moco 系列机器人一致

可以选择对应机器人配置修改结构参数新建；

（2）标定执行器：

进入执行器标定界面，首先复位 PWM 偏差并使能输出，根据机器人构型查

看关节角度是否与单腿设计一致，通过拖动滑条调节到对应角度，同时选择反向

勾选框保证正确的舵机转向；

注：对于软件中不包括的舵机用户可以在该界面中通过修改复位角度和舵机

时间参数进行调节；

（3）复位参数：

进入参数配置界面电机复位参数后写入完成控制器参数的复位；

（4）标定传感器：

在控制器固定完毕后将机器人水平放置，依次点击标定加速度计和标定陀螺

仪，并查看姿态角是否收敛为 0；

（5）测试模式：

进入测试模式界面依次完成各测试模式，在运动学测试中测试期望位置是否

与实际解算一致并通过勾选框配置单腿内外肘构型；在伪力控测试中通过给定末

端力，在不同机器人姿态角度下查看末端运动是否在全局坐标系下；在摆动相测

试中通过给的期望落足点验证摆动腿运动是否正常；在姿态逆解平衡界面通过配

置外扩偏差调节合适的机器人落足区域保证姿态控制稳定；在力控平衡界面，通

过干扰机器人姿态调节 PID 参数整定机器人虚拟伺服的稳定性能；

（6）最终回到参数调整界面，通过遥控机器人前后，调节前后落足偏差与

姿态控制偏差获得稳定的机器人移动效果；

## 11.遥控器与操作说明

控制器能通过四种方式接受外部遥控命令，主要包括 SBUS 航模遥控、串口

上位机遥控、串口无线遥控与 USB 上位机遥控，各功能说明如下：

遥控输入方式 | 功能 | 优先级（1 级最高）

SBUS 输入 | 通过 SBUS 读取航模接收
| 机控制

1 级

串口遥控 | 通过串口 UART1 连接射
| 频通讯链接遥控器

2 级

串口上位机遥控 | 通过串口连接 TTL-USB 模
| 块与上位机通讯，上位机
| 读取USB遥控器发送命令

2 级

USB 上位机遥控 | 通过 USB 口连接主控，上
| 位机读取USB遥控器发送
| 命令

3 级

USB 上位机键盘 | 通过 USB 口连接主控，上
| 位机读取键盘命令控制

4 级

## 12.配置参数保存与读取说明

为实现参数快速的保存与下载，MOCO 上位机支持向 TXT 文档写入和读取参

数，方便用户快速备份、修改和下载已有的参数，界面如下所示：


图 15 参数保存选项

我们提供可直接修改的 TXT 参数文件，用户可以直接在文本力修改对应参

数，如下图所示：


图 16 参数配置文件

机器人菜单提供了主控断电、复位与参数保存的功能，其中强制断电只能在

主界面实现断电，保存参数是保存目前主控内部的参数并非上位机显示的参数：


图 17 机器人快速操作菜单

## 13.软件 Bug 与处理方法

目前上位机仍然存在许多 Bug，目前已知的 Bug 解决方法如下：

（1）串口连接后快速丢失：

解决方法：通过重新插拔转换模块或连线；

（2）控制器参数丢失：

解决方法：实时保存最终文件，读取下载；

（3）长期拖动滑条未响应：

解决方法：快速拖动或者长按滑条左右两侧也可以调节参数，未响应后需要

重新启动 OCU；

## 14.控制器使用与授权

控制器默认烧录机器人控制固件，通过 OCU 配置可以完成对不同机器人构型

的选择和参数的调节，另外用户也可以自己通过 SWD 烧录程序将其作为一个

STM32F4 单片机开发板使用，为保护自主知识产权控制器仍然采用 OLDX 飞控软

件授权的方式，即 MOCO 机器人控制固件仅与官方加工的硬件绑定的方式实现，

用户使用软件需要提供 OCU 上显示的芯片 ID 并获取授权码。

当然我们也提供面向任意同系列单片机和开发板的通用固件，其相关步态功

能和机器人参数会受到限制，具体固件授权影响如下：

授权方式 | 功能
官方控制器+授权 | 完整功能
官方控制器+非授权 | 仅支持腿长 10cm 以下的机器人，且
| 不支持 SLIP 等高级步态功能
非官方控制器+授权 | 如引脚配置满足需求具有完整功
| 能，需单独购买授权码
非官方控制器+非授权 | 暂不支持

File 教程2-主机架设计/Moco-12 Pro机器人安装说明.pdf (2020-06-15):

文档版本 Ver 1.0 | 修正日期 2020/6/1

# MOCO-12 Pro 组装教程文档

## 1. 简介

MOCO-12 Pro 是一个 12 自由度舵机缩比机器人模型，其原型来自于伊利诺

伊大学厄巴纳大学丁博士的电驱动四足机器人，该机器人造型帅气而且体积十分

小可以完全作为桌面级的机器人平台，单腿电机设计也采用了类似 MIT 那种三关

节+连杆集成在跨关节的方式，整体机械结构的集成度十分高，原始机器人采用

了 MPC 控制算法可以说是与 MIT 机器人能相媲美的一个四足机器人，我们提供

的缩比模型在整体结构上较好地模仿了原型结构设计，采用连杆作为主机架，考

虑舵机执行器安装对部分结构进行了修改。


图 1 机器人原型与缩比模型

MOCO-12 Pro 缩比模型整体尺寸很小，内部空间仅能放置 MOCO 通用控制

器机身比例协调相比其他舵机机器人在美观程度上大大提升，受限于本体体积机

载电池容量较小，但可通过外部实时供电的方式实现长时间活动，缩比模型主要

参数如下所示：

表 1 缩比模型主要参数

项目 | 说明 | 备注
机器人长度 | 0.119 m | 髋关节距离
机器人宽度 | 0.342 m | 髋关节距离
侧摆电机偏距 | 0.028 m
大腿长度 | 0.0565 m
小腿长度 | 0.065 m

整机重量 | 300 g 左右 | 包含电池
大腿活动范围 | -45°~145°
小腿活动范围 | 25°~155°
侧摆活动范围 | -35°~34°
电池容量 | 1000 mAh | 8.4V
外部供电 | 尾部 2P 端子 | 8.4V 输入
| | 二极管 1.2V 降压
标配舵机 | GDW9G 舵机 | 180°

## 2. 详细物料

MOCO-12 Pro 主要物料包括本体 3D 打印结构件、MOCO 控制器、螺丝螺母、

舵机、风扇、舵机连杆、机架碳管、电池、供电端子、外部电池盒等，具体物料

明细如下（黄色为可选）：

表 2 结构件 BOM 表

项目 | 说明 | 数量
大腿结构件 | 3D 打印 | 4
小腿杆 | 3D 打印 | 4
足底 | 3D 打印 | 4
足底缓冲 | 手工裁剪 | 4
小腿连杆固定件 | 3D 打印 | 4
舵机连杆 | M2 孔拉杆 40~55mm 10mm

## https://item.taobao.com/item.htm?spm=a1z09.2.0.0.67002e 8d56SfjN&id=558865737444&_u=21klsj899579

| | 4
侧摆电机固定件 | 3D 打印 | 4
主机架固定件（前 后） | 3D 打印 | 2

主机架固定件（中

部）

| 3D 打印 | 2
主机架碳管 | 4mm*2mm *1m （18 cm 切割长度） | 1

## https://item.taobao.com/item.htm?spm=a1z09.2.0.0.67002e 8d56SfjN&id=576541682770&_u=21klsj896710

尾部供电结构件 | 3D 打印 | 1
腹部支撑结构件 | 3D 打印 | 4
侧挡板 1 | 3D 打印 | 2
侧挡板 2 | 3D 打印 | 2
控制器安装结构 件 | 3D 打印 | 1
风扇 | 3 cm 边长 5V

## https://detail.tmall.com/item.htm?id=610677260477&spm=a 1z09.2.0.0.67002e8d56SfjN&_u=21klsj8951a5

1

顶部把手 | 3D 打印 | 2
金属法兰 | 内径 5mm 外径 10mm 厚度 4mm

## https://item.taobao.com/item.htm?spm=a1z0d.7625083.199 8302264.5.5c5f4e69m4Unae&id=613279618315

4

电池仓 | 3D 打印 | 1
开关固定 | 3D 打印 | 1

表 3 螺丝螺母 BOM 表

项目 | 说明 | 数量
M3*6 自攻螺丝 | 舵机固定 | 6*4
M3*16 螺丝 | 大腿与小腿关节固定 | 4*4
M2*10 螺丝 | 小腿舵机拉杆固定 | 8*4
M3*6 自攻螺丝 | 机架碳管固定 | 8
M3*10 自攻螺丝 | 尾部供电固定 | 4
M3*15 自攻螺丝 | 风扇供电固定 | 4
M3*4 螺丝 | 舵机齿轮孔固定 | 8*4
M3 自锁螺母 | \ | 4*4

M2 自锁螺母 | \ | 8*4

表 4 电气件 BOM 表

项目 | 说明 | 数量
舵机 | RS0708 舵机 180°

## https://item.taobao.com/item.htm?spm=a1z09.2.0.0.67 002e8d56SfjN&id=606507148104&_u=21klsj8919ea

12

开关 | https://item.taobao.com/item.htm?spm=a1z09.2.0.0.67 002e8d56SfjN&id=42709116344&_u=21klsj89c9d0

1

机载电池 | 2S 1000mAh https://item.taobao.com/item.htm?spm=a1z09.2.0.0.67 002e8d56SfjN&id=582960890486&_u=21klsj899844

1

外部 18650 电池 | 3200mAh 平头 https://item.taobao.com/item.htm?spm=a1z09.2.0.0.31 8c2e8d786Yq5&id=525673507438&_u=21klsj89f510

2

二极管降压模块 https://item.taobao.com/item.htm?spm=a1z09.2.0.0.67 002e8d56SfjN&id=18725756513&_u=21klsj8900c8

1

机载电池充电器 https://item.taobao.com/item.htm?spm=a1z09.2.0.0.67 002e8d56SfjN&id=538620371117&_u=21klsj89eb4b

1

18650 电池充电器 | 双充电

## https://detail.tmall.com/item.htm?id=566327575224&sp m=a1z09.2.0.0.318c2e8d786Yq5&_u=21klsj89b16e

1

线缆 | 4P 双头

## https://item.taobao.com/item.htm?spm=a1z09.2.0.0.67 002e8d56SfjN&id=528691263571&_u=21klsj897b3f

\

端子连线 | 2P 公母头

## https://detail.tmall.com/item.htm?id=574484456267&sp

\

## m=a1z09.2.0.0.67002e8d56SfjN&_u=21klsj895c24

18650 电池盒 | 18650 电池盒 2 节带开关
| https://detail.tmall.com/item.htm?id=552736465061&sp
| m=a1z09.2.0.0.318c2e8d786Yq5&_u=21klsj8992b4

1

表 5 控制 BOM 表

项目 | 说明 | 数量
MOCO 控制 器 | \ | 1
Micro USB 线 | OCU 上位机连接用 | 1
下载器转接 模块 | 可选 | 1
STlinkV3+TTL 串口 | STlink 可选 https://item.taobao.com/item.htm?spm=a1z09.2.0.0.67002e8d 56SfjN&id=597042583224&_u=21klsj8977cb | 1
USB 转接板 | \ | 1
遥控器 | 北通深夜版 https://detail.tmall.com/item.htm?id=38896089959&spm=a1z0 9.2.0.0.67002e8d56SfjN&_u=21klsj8918f8 | 1

舵机调试模

块

## https://item.taobao.com/item.htm?spm=a230r.1.14.131.1b301 b7abU5aC9&id=614865935834&ns=1&abbucket=19#detail

1

表 6 工具类 BOM 表

项目 | 说明 | 数量
十字螺丝刀 | \ | 1
尖嘴钳 | \ | 1
502 胶水 | \ | 1

锯子 | \ | 1
焊接工具 | \ | 1
剥线钳 | \ | 1
绝缘胶带 | \ | 1
胶枪 | \ | 1
上色工具 | 高达涂装笔

## https://item.taobao.com/item.htm?spm=a1z09.2.0.0.67002e 8d56SfjN&id=591467609648&_u=21klsj8980e8

1

## 3. 电气连接

MOCO-12 Pro 电气部分连接主要包括供电与主控的连接、舵机与主控的连接、

以及其他模块与主控的连接，推荐的电气连接方式如下图所示：


图 2 电气总体布局


图 3 推荐连线

如上图所示的推荐连线，首先各舵机依据腿号与对应 PWM 口连接，通过

SWD 口下载和更新固件，USB 口通过转换板与 PC 上位机连接，PC 同时接入遥

控器控制机器人；供电部分机载电池直接与总开关连接，外部供电 18650 电池安

装与串联电池盒通过二极管降压模块降低电压减少长时间工作舵机发热后与总

开关连接，总开关正负极与控制板焊盘或者引出的电源线连接，主控供电则从开

关前直接从电源引出一路杜邦线连接供电引脚，避免开关关闭主控无法供电。

## 4. 组装与调试教程

MOCO-12 Pro 组装的过程可以分为结构上色、主控焊接、主控安装、单腿组

装、机架单腿组装、机架固定、装饰件安装与电气连接几个步骤，各步骤具体过

程如下：

## 4.1 结构件上色

对 3D 打印结构件进行打磨、抛光并采用高达涂装笔或者喷涂工具对结构件

上色；

## 4.2 主控焊接与安装

（1）焊接机器人 JST 母头+与总开关；

（2）焊接外部电池盒+输出与二级管+，焊接二极管+与外部供电 JST 公头+，

JST 公头-与电池盒-焊接；

（3）焊接总开关与主控供电焊盘+，JST 母头-与主控焊盘-连接；

（4）单独从 JST 供电头引出一路电源+并使用 2.54 杜邦头连接主控供电引

脚；


（4）使用胶枪或 3M 胶把主控固定在控制器固定件上，并将其卡入机架碳

管；

## 4.3 单腿组装

（1）将舵机固定在大腿上并拧入螺丝固定；

（2）将小腿杆与小腿固定件和足底组装，并用螺丝与大腿组装；

（3）将舵机与侧摆固定件组装并拧入螺丝；

（4）裁剪单臂舵盘使用 502 胶水固定在大腿和侧摆固定件对应凹槽处；

（5）使用上位机输出复位角度（舵机偏差均为 0），依据单腿坐标系与复位

角度粗略组装大腿与侧摆舵机，拧入螺丝固定大腿；

（6）采用相同方法复位小腿舵机并安装舵机摇臂，最好用螺丝固定；

（7）裁剪小腿舵机摇臂多余部分并使用电钻或其他钻孔设备扩张最外侧的

圆孔；

（8）使用拉杆连接大小腿并拧上自锁螺母；

（9）使用同样方法组装其他腿；

## 4.4 单腿与机架组装

（1）将法兰安入机架前固定件的圆槽处；

（2）将侧摆舵机安装在中部固定件；

（3）用上位机或舵机调试模块复位侧摆舵机并将单腿部分组装；

（4）将碳管插入机架固定件边缘四个孔中；

（5）依次安装各固定件、主控固定件和另外一侧单腿，安装主控时注意机

头朝向；

（6）调节尺寸保证侧摆部分牢固、侧摆舵机间隙小、摩擦小；

（7）将多余碳管截去并打磨末端；

## 4.5 机架与装饰件组装

（1）安装底部电池盒，拧入机架固定螺丝；

（2）安装顶部扶手，拧入机架固定螺丝；

（3）依据舵机关节关系连接舵机，并整理走线；

（4）安装腹部支架并固定装饰挡板；

（5）安装风扇与尾部供电固定件；

（6）连接风扇正负与主控引脚；


## 4.6 机器人配置与调试

（1）上电测试

（2）运动学测试

（3）伪逆测试

（4）摆动测试

（5）平衡逆解测试

（6）平衡伪逆测试与姿态参数调节

## 4.7 机器人遥控测试

（1）遥控器通道映射与状态切换逻辑

（2）遥控测试与参数调节

## 5. 机器人的二次开发与无线控制

## 5.1 无线遥控

如需要对机器人进行无线遥控需要购买串口无线数传模块并与主控上串口 1

端子连接（默认波特率为 115200），此时连接上位机仍然可以通过遥控和键盘

发送命令但相关数据和标定功能受通讯带宽影响会被屏蔽或简化，具体功能如下

表所示：

表 6 无线通讯时上位机功能

功能 | 说明
遥控 | 支持
主界面 | 仅显示姿态、速度和基础信息，且频率下降
传感器标定界面 | 不支持
向导界面 | 不支持
执行器标定界面 | 不支持
测试界面 | 不支持
控制界面 | 支持部分功能

参数调节界面 | 支持

## 5.2 二次开发（底盘模式）

主控的二次开发接口同样为串口 1（默认波特率为 115200），通过连接树莓

派或其他控制器能将机器人当做移动底盘基于 SDK 完成对本体速度、姿态与步态

模式的控制，具体通讯协议如下：

表 6 速度控制命令

功能 | 说明
遥控 | 支持
主界面 | 仅显示姿态、速度和基础信息，且频率下降
传感器标定界面 | 不支持
向导界面 | 不支持
执行器标定界面 | 不支持
测试界面 | 不支持
控制界面 | 支持部分功能
参数调节界面 | 支持

## 5.3 二次开发（步态算法模式）

同样可以对主控步态进行二次开发，其需要使用 USB 连接主控，基于我们提

供的开源 Python 程序完成对底层主控参数的读取，通过在 PC 机上计算控制命令

并实时下发的方式进行四足机器人步态控制算法的研究，目前该功能仍在开发

中；

## 6. 存在的问题

（1）大腿角度过高时会卡在腹部保护机架处；

（2）小腿足底设计待优化，无足底传感器；

（3）大腿结构件在舵机长期发热后变形；

（4）主控安装位置较深，PWM 连线与更换麻烦；

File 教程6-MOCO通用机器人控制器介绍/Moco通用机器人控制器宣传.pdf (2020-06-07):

文档版本 Ver 1.0 | 修正日期 2020/6/1

# MOCO 通用机器人控制器内测招募

# （首批仅 20 人）

## 首批内测核心用户招募

MOCO 通用机器人控制器是一个国人原创的完整机器人项目，力图打破目前

国内优秀四足机器人项目匮乏的现状，希望能超越国外极客打造国人独创的算法

与创新的玩法，新控制器相比以其有以下几个重大突破：

+支持机器人向导设置（用户可以通过向导的方式配置机器人）

+支持在线角度标定（用户可以在线调节偏差加快舵机标定）

+支持参数在线调节（用户可以在线调参，快速适配不同尺寸机器人）

+支持向导式模块测试（向导式测试帮助用户快速验证优化机器人参数）

+支持参数本地保存（快速下载参数，免去丢失烦恼）

现招募首批核心测试用户，加入本次活动请联系群主，本次测试用户具有如下优

惠：

（1）以成本价购买控制器

（2）免费软件授权

（3）内部 QQ 群一对一指导

## （4）MOCO-12 Pro 测试版 3D 打印资料

## 1. 简介

MOCO 通用机器人控制器是一个面向四足、双足、六足与无人机通用的嵌入

式控制器，其设计的理念是最大程度降低机器人爱好者软件开发的工作，借鉴乐

高 MOC 构建的理念提供高性能、易用、多兼容、可快速定制的机器人/模型控制

器。MOCO 通用机器人控制器本质上并非一个开源飞控或机器人控制器，为提高

高性能的控制效果，不同构型的机器人均采用了很多原创的算法并经过很长时间

的改进，所以为保护知识产权抱歉无法为用户提供完全开源的软件代码，你可以

理解为这个控制器和 DJI 早期 NAZA 飞控一样不具有完全的底层代码开发性但是

配套了针对特定机器人构型所需易用的上位机能让用户快速地完成参数配置与

驱动器标定，同时我们也提供丰富的二次开发接口从顶层的机器人本体位姿期望

到底层的驱动器输出和关节角度均可以通过通讯协议设置，为电子开发爱好者提

供一个桌面级的机器人底盘实现 SLAM、人工智能和机器人视觉的开发。当然你

如果对开发不感兴趣在安装完成后控制器已经能完成出色到的控制效果，你只需

要关注结果设计与涂装专注于缩比模型的构建，当然它是具有高性能可动的缩比

模型！

## 2. 丰富的控制器硬件资源

MOCO 控制器采用 STM32 单片机作为 CPU 板载基本的陀螺仪与加速度计，

预留 12 路 PWM 输出与 4 路模拟量和开关输入，外部信号输入预留一路 SBUS 接

收机和 2 路串口，板载 5V DCDC 各 PWM 引脚供电采用外部电池输入同时具有 1

路电源使能信号输出，预留一路 USB 调试接口实现与上位机高速通讯，控制器

主板如下图所示。


图 1 MOCO 通用机器人控制器

主控尺寸小于 5*3cm 能集成到桌面级的机器人系统中，控制器各硬件资源如

下表所示：

表 1 MOCO 通用机器人硬件资源

项目 | 性能 | 备注
STM32F405RGT | 168Mhz 1K Flash | 主控芯片
LSM6DS33 | 加速度计+陀螺仪 | 6 轴姿态传感器
W25X16 | 16M-bits Flash | 参数存储芯片
AS1364-BTDT-33 | 3.3V 稳压 | 单片机降压
PWM 接口数量 | 12 个 | 外部供电
串口 | 2 路 | Uart1 Uart4
USB | 1 路 | OCU 通讯

SWD | 1 路 | 5V 供电
模拟/开关输入 | 4 路 | 3.3V 逻辑 5V 供电
SBUS | 1 路 | 5V 供电
LED | 2 个 | 状态显示
电源输入范围 | 6~20V | 5V 内部降压

## 3. 多功能、多模块、高扩展接口设计

控制器电气连接主要完成 PWM 与舵机或无刷电机驱动器的连接，PWM 供电

线与电池的连接，主控供电线与电池的连接，遥控器的连接，USB 与上位机的连

接，外扩模块与串口的连接，则具体连线示意图如下所示。


图 3 控制器电气连接

如上图所示，PWM 接口可以直接连接舵机驱动或者连接电子调速器驱动无

刷电机，AD 接口可以连接微动开关采集足底开关信息，OCU 端子可以选择连接

无线遥控器接收器或者直接连接 SWD/TTL 转串口一体模块，USB 端口则连接 OCU，

上述遥控输入 SBUS 优先级高于串口、串口高于 OCU。供电端电池同时给板子

DCDC 与 PWM 引脚供电，供电口输出的开关信号可以用于控制继电器开关动力

电源，同时也可以增加一个主动开关。

## 4. 易配置、快速上手、免软件调试

MOCO 通用 OCU 上位机是支持 MOCO 机器人控制器进行快速配置与参数调

节的跨平台软件，其基于 Python 内核能部署于 Windows 与 Ubuntu 系统。上位

机支持对机器人构型的选择可以快速完成 MOCO 系列四足机器人的建立，同时

还支持用户基于机器人构型参数快速自定义，同时上位机集成参数在线调节功能

能快速实现参数的整定并配有波形显示为姿态控制参数整定提供可视化指标。为

方便用户测试上位机提供了对舵机输出的标定界面用户能快速完成角度偏差标

定与转向标定，同时提供完善的测试步骤在机器人标定配置完成后用户依据测试

流程既可以完成对机器人稳定性的快速调试，为实现参数保存上位机也支持对配

置参数的本地存储与快速写入，相比上一代代码调节的方式大大加快机器人的调

试！

OCU 上位机主要分为主界面、机器人向导、参数设置、执行器标定、传感器

标定、测试模式与控制模式几大界面，各界面主要功能如下：

（1）主界面：

该界面主要完成机器人状态的显示，包括姿态、位置、速度、控制模式等，

同时以图像的模式显示各关键角度，同时可以在主界面完成串口配置以及对波形

曲线的查看。

（2）机器人向导：

该界面主要完成对机器人快速的向导式配置，可以选择 Moco 系列机器人实

现对官方特定构型机器人参数的配置和下载，另外也可以通过 DIY 模式依据用户

自己的机器人参数进行设置。

（3）参数配置界面：

该界面主要对机器人内部参数的在线整定和保存，可以完成对机器人典型位

姿控制增益，落足、姿态偏差的调节，也可以实现对参数的快速恢复出厂设置。

（3）执行器标定界面：

该界面主要完成对 12 路 PWM 输出的快速标定，包括各 PWM 输出的偏差以

及执行器旋转的方向，同时也可以完成对舵机时间参数的标定让用户使用自己的

舵机数据。

（4）传感器标定界面：

该界面主要完成对板载 IMU 的标定包括对其测量偏差和尺度偏差，对磁场的

在线拟合标定以及 GPS 和 IMU 安装位置角度的标定。

（5）测试模式界面：

该界面主要完成在机器人配置完成后对各独立功能的快速测试来验证参数

配置的正确性，包括正逆运动学、伪逆力控和位姿调节等。

（6）控制模式界面：

该界面主要为用户提供一个在无遥控器下快速测试机器人的方法，可以实际

基于按键与键盘操作下机器人速度、姿态和步态的快速调节。

该界面主要完成机器人状态的显示，包括姿态、位置、速度、控制模式等，

同时以图像的模式显示各关键角度，同时可以在主界面完成串口配置以及对波形

曲线的查看，具体功能如下：


图 4 定制四足机器人专用上位机

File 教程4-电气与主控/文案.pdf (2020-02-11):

# MoCo-12 四足机器人 缩比模型系列教程3

## 《模型组装与涂装》

## 华北舵狗王

课程资料链接：https://github.com/golaced/Quadruped-Robot-Moco-12- 知乎链接：https://www.zhihu.com/people/golaced

# 教程规划


# - 缩比模型介绍 - 缩比模型结构设计 - 缩比模型加工与组装


# - 缩比模型控制器电气设计 - 机器人步态与控制算法设计 - 静态演示与缩比场景设计

# 缩比模型对象


https://www.youtube.com/watch?v=rzFrpeMpv8Mhttps://ieeexplore.ieee.org/author/37086268690

## - 经典论文


模型设计 | 切片 | 打印 | 打磨抛光
书籍推荐 | 知乎推荐

# 模型打印&切片


PLA打印机 | 晶格热床 玻璃板

光固化打印机

紫外固化

切片软件

## 模型下载

https://www.thingiverse.com/thing:3445283

https://hackaday.io/project/168506-dante

## 开源项目

ＰＬＡ：210-225 度 ＡＢＳ：230-245 度; · PLA制成的3D模型更适合 用来展示不适合使用，ABS普 遍强度更高; · 但PLA比ABS更容易塑形， 模型光泽性好，色彩艳丽，可 降解安全环保; CURA 15.4参考设置

# 打印件后处理

3D打印件 | 光滑液 | 烙铁烫平 | 打磨抛光


https://www.youtube.com/watch?v=u_hGU09Q22k&t=260s

原始件 | 仅打磨 | 仅光滑液

专业模型处理流程

https://www.youtube.com/watch?v=vQc5TBPF8uw

有毒气体; 手套防护; 涂刷不均匀

https://www.youtube.com/watch?v=0vgynnYzo08


3D打印笔 | 提升原始打印精度
线条造型 | 发光造型
块粘结 | 细节修复

提高STL文件精度

https://www.youtube.com/watch?v=CzW45MphcK4

修改打印配置

后期手工处理

Iron | 层高

默认打印; 低模+Iron（Top）; 高模+Iron（Top）; 高模+Iron（0.2）; 高模+Iron（0.15）

高模+Iron（ALL）

# 模型组装


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
# 总花销<1200RMB


# 机器人基本运动学


运动学正解

运动学逆解

机器人动力学

由关节角度计算腿末端在跨关节坐标系{H}下的三维位置 （用于机器人位姿估计和速度估计）

由末端位置解算各关节角度
（用于机器人摆动腿轨迹跟踪，基于位置的姿态调节和控制）

由力计算关节所需力矩，计算机构转动惯量
（用于机器人力控输出，静力学和力矩平衡分析）

# 运动学正解


- DH法：实际就是立体几何成像中常用的平移矩阵变换 1）原理清晰，易于推广
2）矩阵运算存在冗余计算量
- 几何法：借助常用的Sin、Cos和余弦定理求取数值解 1）速度快原理简单
2）推导复杂，角度正负号和方向容易混淆

# DH坐标系法


坐标系B原点在坐标系A中的坐标 | 坐标系A原点在坐标系B中的位置
绘制连杆 | 列DH表 | 矩阵乘法

Sita：关节角度
d：关节宽度
a：关节长度
alfa：关节偏角

## DH表


# 几何法

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
1 A0

1

# sin

# cos

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
A1T | 2 2
A0
1 A0

1

2 A0

2

# sin

# cos

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
1 | 1
A1 | 1 | 1
A0
sin | cos
cos | sin
R
θ | θ
θ | θ

2
1

1
0

# 2 T0 = T T

# 运动学逆解

## - 闭式解：直接采用几何知识求解 1）速度快，仅需要正余旋函数运算 2）无奇异，位置角度一一对应

## - 数值解：采用递推和迭代方法求解 1）效率低，受初始值影响 2）多解筛选（能耗，速度，避障）


https://blog.csdn.net/aic1999/article/details/82586869

## 摆动腿控制

位姿估计 | 位姿控制


[ | ]
[ | ] | [ | ]
([ | ])
( | )
PWM | 2 | 1 | 2 | 3
1 | 2 | 3 | 1 | { }

### θ θ θ

### θ θ θ

f

## f x y z

## x y z

H

t

=

=

=

舵机

摆动轨迹

完成对末端轨迹实时的跟踪控制：

计算质心的机械角度，机械位置：

计算支撑腿所需腿长：

(p | )
LS(p | )

{B}

{B}

支撑腿

支撑腿
质心位置

姿态角
= f

=

p | ( | )

{
支

B
撑

}

| 腿 = f 姿态角，质心位置 | 质心速度

角速度

# 雅克比动力学

## - 雅克比矩阵：机器人基础微分运动学，完成末端速度与关节 角速度的空间映射 1）由末端期望速度计算关节期望角度 2）由末端期望力输出计算关节力矩

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
1 | 2
1 | 2
z | z
x | x
p
θ | θ
θ | θ
θ

J θ
- p = J

速度雅克比换算

J F

T τ =

1）关节无摩擦
2）忽略连杆质量/惯量

虚功原理/广义力


https://wenku.baidu.com/view/3026e4afaff8941ea76e58fafab069dc50224727.html

力矩雅克比换算

# Matlab Coder代码导出

p

1

- - θ = J
T 1 T

# (J ) (J J ) J

# inv =


注意：
1)保证除法分母不为0
2)反正余弦函数输入限幅在-1~1
3)最终雅克比输出判断NAN做好保护

http://news.eeworld.com.cn/mp/e/a51724.jspx

N×N求逆函数; 卡尔曼滤波器; 运动学正逆解

# 下一节教程内容

# - 1）AltiumDesigner9 原理图设计介绍 - 2）AltiumDesigner9 PCB设计介绍 - 3）基于STM32F4的行走主控设计介绍 - 4）物料导出采购与PCB加工焊接 - 5）缩比模型供电与电气系统设计


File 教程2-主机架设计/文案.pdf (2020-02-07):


# MoCo-12 四足机器人 缩比模型系列教程2

## 《机架建模》

## 华北舵狗王

2020/2/7

课程资料链接：https://github.com/golaced/Quadruped-Robot-Moco-12- 知乎链接：https://www.zhihu.com/people/golaced

# 教程规划


# - 缩比模型介绍 - 缩比模型结构设计 - 缩比模型加工与组装


# - 缩比模型电气与控制器设计 - 模型步态与算法设计 - 模型配件与静态场景设计

# 缩比模型对象


https://www.youtube.com/watch?v=rzFrpeMpv8Mhttps://ieeexplore.ieee.org/author/37086268690


主机架碳管

“背靠背”跨
关节结构

并联连杆

小腿舵机侧装

小腿舵机嵌入

# SW建模基本操作

# - 1）大腿建模 - 2）小腿足底建模 - 3）胯关节建模 - 4）单腿装配 - 5）主机架装配测试 - 6）主框架建模 - 7）装饰件建模

# 大腿建模

建模关键点： 1）小腿固定卡槽需要紧密，降低虚位引起的足端误差 2）大小腿长度需要兼顾舵机扭矩1kg/cm约等于0.1N/m 3）舵机和摇臂固定牢固减少关节角度控制误差 4）减少大小腿间机构摩擦，降低舵机负载; 建模步骤： 1）建立大腿主体 2）建立舵机卡槽 3）建立摇臂卡槽 4）优化大腿造型 5）建立辅助定位圆槽

# 小腿建模

建模关键点： 1）足底需要具有较大的宽度以提高步态稳定性 2）足底需要具有一定的缓冲性能，减小落足冲击对 IMU数据融合带来的加速度尖峰 3）足底具有较高的摩擦力，由于舵狗为开环控制， 机器人速度控制反馈如在打滑的情况下会出现失真; 建模步骤： 1）建立小腿固定 2）建立小腿连杆 3）建立足底 4）优化模型造型 5）建立辅助定位圆槽; 并联连杆; 串联连杆; 舵机串联

# 胯关节建模

建模关键点： 1）保证关节连接轴线对称 2）跨关节舵机固定和摇臂固定牢靠减少角度虚位 3）机架连杆轴线同心; 建模步骤： 1）建立大腿舵机固定 2）建立跨关节舵机固定 3）建立前置卡槽 4）优化模型造型 5）建立辅助定位圆槽; 辅助调节 横滚; 增加足 底宽度; 横滚轴控制; 侧摆角度; 左右侧腿 长度

https://www.youtube.com/watch?v=9PugfVSbnAg

# 单腿装配


装配关键点：
1）校核各腿关节可动范围
2）查找结构干涉位置
3）确定单腿坐标系
大腿：-45°~75° | 侧摆：-25°~35°
小腿：20°~165°

x

z

y

z

# 主机架装配测试


x

y

机头

x

z

# 装饰件建模


前置风扇

侧面挡板

大腿装饰

# 下一个视频内容

# - 1）机架打印 - 2）模组涂装 - 3）打磨组装 - 4）单腿运动学推导


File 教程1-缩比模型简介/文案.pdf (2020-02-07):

# MoCo-12 四足机器人 缩比模型系列教程1

## 华北舵狗王

2020/2/5

# 教程规划

## - 缩比模型介绍 - 缩比模型结构设计 - 缩比模型加工与组装 - 缩比模型电气与控制器设计 - 模型步态与算法设计 - 模型配件与静态场景设计

# 缩比模型对象

# - YanRan Ding


https://www.youtube.com/watch?v=rzFrpeMpv8M

## 伊利诺伊大学厄巴纳

https://ieeexplore.ieee.org/author/37086268690


https://a360.co/345RKVb

主机架碳管

“背靠背”跨
关节结构

并联连杆

小腿舵机侧装

小腿舵机嵌入

# 四足经典算法介绍

## - Marc Raibert 三通道解耦控制


## 经典书籍《Legged Robots That Balance 》


https://zhuanlan.zhihu.com/p/97377338

### 落足点选择+步态相序规划+虚拟伺服力控

刚体控制 | 忽略腿部质量


俯仰角 | 弹跳高度 | 速度

跨关节

液压+弹簧 姿态调节： 在支撑相中控制跨关节扭矩实现对姿态角的调节

### 弹跳高度：

| 压缩伸长弹簧，弹簧行程与刚度关系等效能量补 偿，抵消重力的基础上提供飞行所需重力势能， 实现高度调节

### 前进速度：

| 飞行过程中无前向加速度，通过调节落足点与中 性点的偏差在支撑过程中产生前后加速度实现速 度的控制

## 核心理念：速度控制->落足点控制

落足点<中性点 加速; 落足点>中性点 减速; 缺少支撑相力控制; 速度控制效果差; 误差PD控制

( ) 2
s
f | p | d

xT

### x = + K x - x

- 1. 落足点规划需要机器人精确的状态反馈


2. 伺服力控需要机器人精确运动学参数

### 需要的基本知识：

### 两个关键问题：

1.机器人动力学和运动学知识
1）正解逆解（DH坐标系法，数值法）
2）机器人力控原理，雅克比矩阵求解
3）阻抗控制原理


2.控制理论
1）PID控制原理
2）数据融合算法（Kalman滤波）

3.软件工程
1）基本的编程语言
2）嵌入式开发环境

# 模型主体结构设计

### - 使用工具：SoliderWork2018


### - 主要工具：

- 1）拉伸
- 2）切割

### - 3）圆角、倒角

- 4）镜像
- 5）装配

大昆打印机; 晶格热床 玻璃板

### - 加工设备：3D打印机

视频教程：https://www.bilibili.com/video/av41652358?p=16


购置材料： 1）碳管 2）模型上色工具 3）18650电池 4）舵机 | 5）舵机连杆 6）树莓派 7）摄像头 8）减震软垫

PWM舵机; 总线舵机; 高达马克笔; 1）速度快 2）扭矩大 3）钢齿; 1）无法卸力 2）PWM精度 3）无反馈; 1）有反馈 2）软件卸力; 1）速度慢 2）需节点模块

高达模型涂装：https://www.bilibili.com/video/av54853365

# 关键部件建模要领

大腿小腿; 1）小腿固定卡槽需要紧密放置虚位引起的足端 误差 2）大小腿长度需要兼顾舵机扭矩1kg/cm约等于 0.1N/m 3）舵机和摇臂固定牢固减少关节角度控制误差 4）减少大小腿间机构摩擦，降低舵机负载; 1）足底需要具有较大的宽度以提高步态稳定性 2）足底需要具有一定的缓冲性能，减小落足冲 击对IMU数据融合带来的加速度尖峰 3）足底具有较高的摩擦力，由于舵狗为开环控 制，机器人速度控制反馈如在打滑的情况下会出 现失真

连杆机构


跨关节固定

1）连杆传动固定牢固，减少小腿足底由于安装
误差引起的虚位
2）连杆末端与舵机摇臂平行度好，以减少摇臂
角度与小腿角度间的非线性关系

1）跨关节固定尽量保证与大小腿旋转关节同轴，
减低运动学解算的复杂度
2）侧摆角度具有限位保护，侧摆角度范围在
30~40°间
3）减少固定间与侧摆机构的摩擦力，降低侧摆
运动阻力

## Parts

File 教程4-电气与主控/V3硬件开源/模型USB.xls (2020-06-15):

Comment | Description | Designator | Footprint | LibRef | Quantity
USB-B(Mini) |  | USB | Micro_USB | USB5 | 1
USB-B(Mini) |  | USB1 | USB/SM0.8-6H5_M | USB5 | 1
Header 4 | 卧贴端子 | USB_L, USB_R | SH1.0-4P | Header 4 | 2

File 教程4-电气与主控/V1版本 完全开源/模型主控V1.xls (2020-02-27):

Comment | Description | Designator | Footprint | Quantity
AS1364-BTDT-33 |  | *U1 | TDFN-8 | 1
BEEP | 贴片蜂鸣器 | BEEP? | DET402 | 1
0.1UF | 贴片电容 | C1, C14, C15, C16, C17, C18 | C 0402 | 6
1UF | 贴片电容 | C2 | C 0402 | 1
2.2UF | 贴片电容 | C3, C4 | C0603 | 2
10NF | 贴片电容 | C5 | C 0402 | 1
20PF | 贴片电容 | C6, C7 | C 0402 | 2
0.1UF | 贴片电容 | C8, C9 | C0603 | 2
4.7uf | 贴片电容 | C11, C13 | C0603 | 2
10nf | 贴片电容 | C12 | C0603 | 1
100uF | 贴片电容 | C19 | C0603 | 1
NC | 贴片电容 | C20, C21, C23, C24 | C0603 | 4
BAT54WS | 单肖特基二极管 | D1, D2 | SOD-323 | 2
IN4733 5.1V | Zener Diode | D7 | 1n4148-SOD123 | 1
LED1 | 1,2,3,4 红色 5,6,7,8 绿色 9,10,11,12 蓝色 | DS1, DS2, DS3, DS4, DS5, DS6, DS7, DS8, DS9, DS10, DS11, DS12 | 0603_LED | 12
Header 4 | 立贴端子 | FLOW1, POWER, RADIO1 | JST_GH_V4 | 3 | 配双头10cm线
Header 6 | 立贴端子 | GPS1 | JST_GH_V6 | 1
LSM6DS33 |  | LSM1 | LSM6DS33 | 1
Header 8 | NRF模组 | NRF1 | NRF | 1 | https://item.taobao.com/item.htm?spm=a1z10.3-c-s.w4002-18876255512.22.11fc2184i19zr6&id=543459799531
Header 3 | 2.54排针弯向板边缘 | P15 | HDR1X3 | 1
Header 3 | 2.54排针立 | P1, P2, P3, P4, P5, P6, P7, P8, P9, P10, P11, P12, P13, P14, P16, P17 | HDR1X3 | 16
S8050 | 8050/BCW846/BCW847 | Q1, Q2, Q3, Q4, Q5, Q6, Q7, Q8 | SOT-23R | 8
10K | 贴片电阻 | R1, R6, R7, R8, R39 | R 0402 | 5
10R | 贴片电阻 | R2, R4 | R 0402 | 2
1K | 贴片电阻 | R3, R26, R27, R37, R38, R42, R43 | R0603 | 7
10K | 贴片电阻 | R5, R25 | R0603 | 2
100R | 贴片电阻 | R9, R10, R11, R12, R13, R14 | R 0402 | 6
100K | 贴片电阻 | R15 | R0603 | 1
1K | 贴片电阻 | R16, R17, R18, R19, R20, R21 | R 0402 | 6
560R | 贴片电阻 | R22, R23, R24, R28, R29, R30, R31, R32, R33, R34, R35, R36, R40 | R 0402 | 13
Header 4 | 卧贴端子 | SWD1 | SH1.0-4P | 1 | 配10cm双头线
STM32F405RGT6 |  | U1 | LQFP64_M | 1
W25X16 | W25X16;SST25VF016;MX25L1605 | U2 | W25Q32FVZPIG | 1
USB-B(Mini) | 卧贴microUSB | USB | Micro_USB | 1
MHDR1X19 | 排针 | V1, V2, | MHDR1X19 | 4
MHDR1X19 | 母座 | V11, V22 | MHDR1X19 | 4
8MHZ | Crystal Oscillator | X1 | PXCL | 1

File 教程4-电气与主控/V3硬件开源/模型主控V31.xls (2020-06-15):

Comment | Description | Designator | Footprint | Quantity
AS1364-BTDT-33 |  | *U1 | TDFN-8 | 1
2.2UF | 贴片电池 | C3, C4 | C0603 | 2
10NF | 贴片电池 | C5 | C 0402 | 1
20PF | 贴片电池 | C6, C7 | C 0402 | 2
0.1UF | 贴片电池 | C9 | C0603 | 1
0.1UF | 贴片电池 | C10, C11, C12, C13, C18 | C 0402 | 5
4.7uf | 贴片电池 | C14 | C0603 | 1
10nf | 贴片电池 | C15 | C0603 | 1
100uF | 贴片电池 | C19 | C0603 | 1
Header 4 | 2.54排针 | DCDC1 | HDR1X4 | 1
LED1 | 红色 与 蓝色 | DS2, DS3 | 0603_LED | 2
Header 4 | 立贴端子 | IDLE1, RADIO1 | JST_GH_V4 | 2 | 配双头10cm线
LSM6DS33 |  | LSM1 | LSM6DS33 | 1
Header 3 | 2.54排针 | P1, P2, P3, P4, P5, P6, P7, P8, P9, P10, P11, P12, P13, P14, P15, P16, P17, P18 | HDR1X3 | 18
S8050 | 8050/BCW846/BCW847 | Q1 | SOT-23R | 1
10K | 贴片电阻 | R1, R4, R6, R8 | R 0402 | 4
100K | 贴片电阻 | R7 | R0603 | 1
100R | 贴片电阻 | R9, R30 | R 0402 | 2
560R | 贴片电阻 | R10, R11, R12, R13, R17, R18, R19, R20, R21, R22, R23, R24, R25 | R 0402 | 13
10K | 贴片电阻 | R14 | R0603 | 1
1K | 贴片电阻 | R15, R16 | R0603 | 2
1K | 贴片电阻 | R26, R27, R28, R29 | R 0402 | 4
Header 4 | 立贴端子 | SWD1, USB_L | SH1.0-4P - up | 2 | 配双头5cm线
STM32F405RGT6 |  | U1 | LQFP64_M | 1
W25X16 | W25X16;SST25VF016;MX25L1605 | U2 | W25Q32FVZPIG | 1
8MHZ | Crystal Oscillator | X1 | PXCL | 1

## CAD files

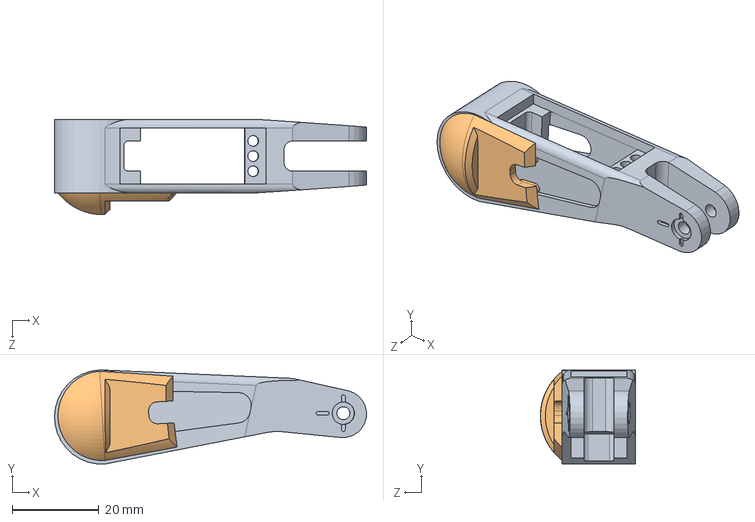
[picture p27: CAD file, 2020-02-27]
教程2-主机架设计/1.0 SW文件/装配体1.SLDASM
72.1 x 21.7 x 22.0 mm
大腿_舵机
大腿_舵机保护

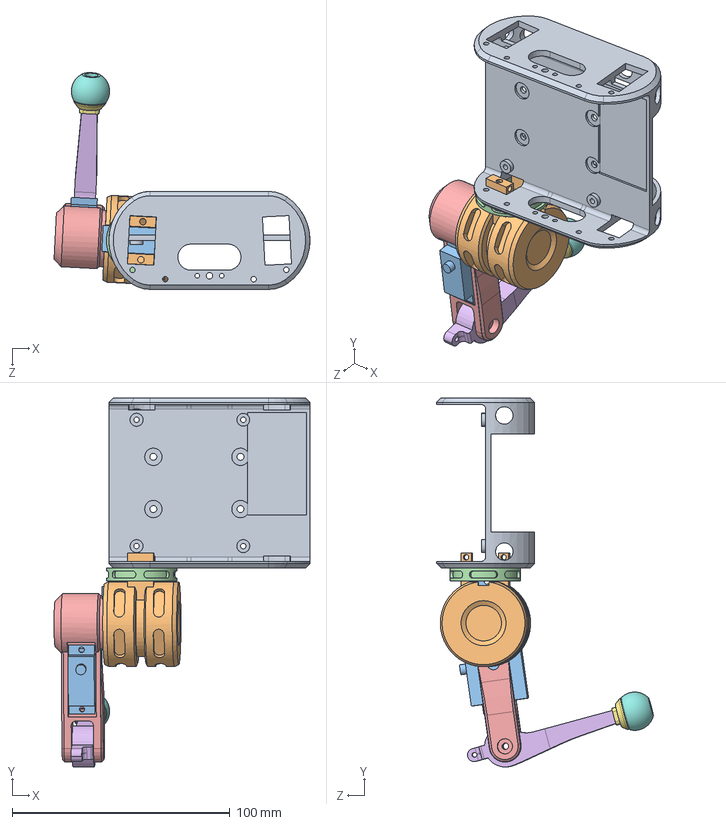
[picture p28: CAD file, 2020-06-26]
教程2-主机架设计/moco-8 Test Verison/moco-8-cheetha.SLDASM
117.5 x 169.4 x 99.6 mm
机架上盖
大腿固定
9g舵机 x 2
大腿固定2
小腿舵机
小腿
足底固定
足底

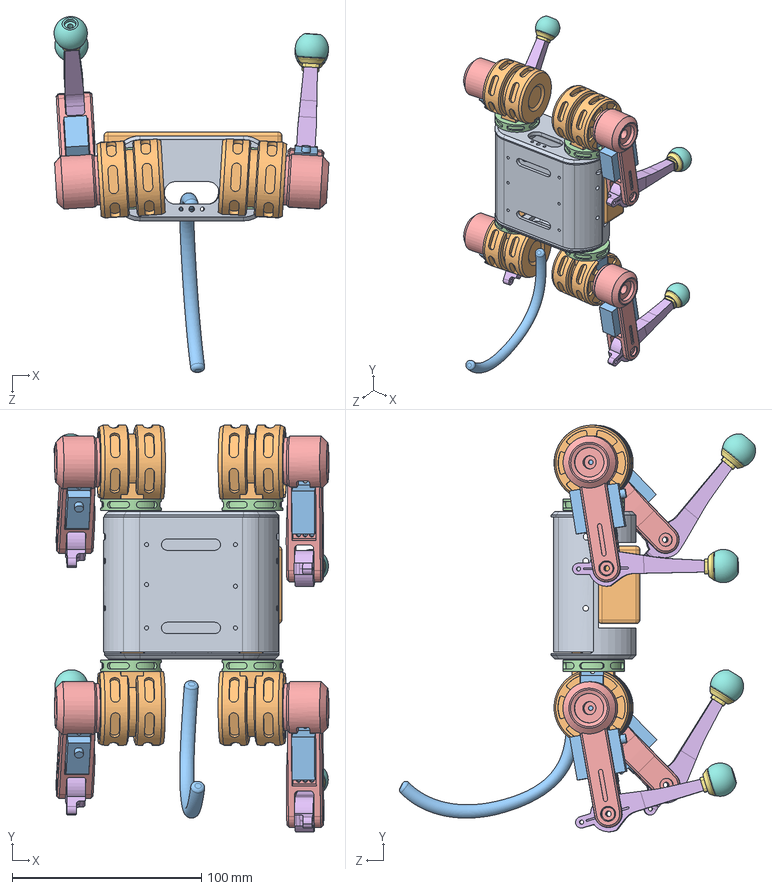
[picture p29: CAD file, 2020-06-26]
教程2-主机架设计/moco-8 Test Verison/moco-8.SLDASM
145.3 x 214.9 x 188.1 mm
机架上盖
大腿固定 x 4
9g舵机 x 8
大腿固定2 x 4
小腿舵机 x 4
小腿 x 4
足底固定 x 4
足底 x 4
顶盖
电池
尾巴

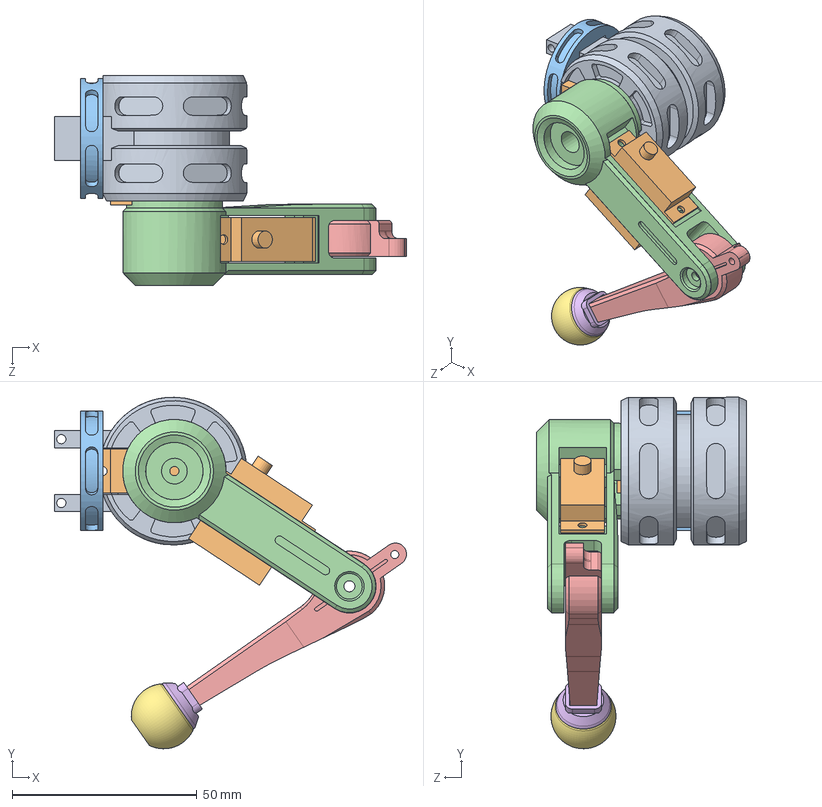
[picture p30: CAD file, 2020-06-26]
教程2-主机架设计/moco-8 Test Verison/大腿装配.SLDASM
95.3 x 95.2 x 56.8 mm
大腿固定
9g舵机 x 2
侧摆电机
大腿
小腿
足底固定
足底

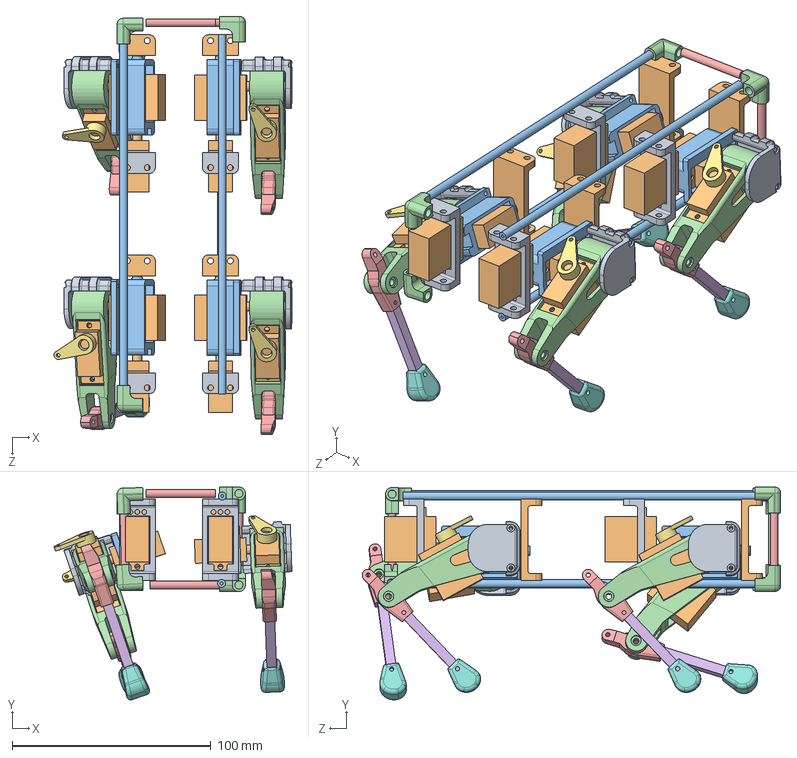
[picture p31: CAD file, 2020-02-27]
教程2-主机架设计/1.0 SW文件/moco-12.SLDASM
119.9 x 107.2 x 210.8 mm
跨舵机固定 x 4
9g舵机 x 12
大腿舵机固定 x 4
大腿_舵机 x 4
小腿连杆固定1 x 4
小腿杆 x 4
摇臂1 x 4
足底 x 4
大腿圆盘固定 x 4
跨固定1 x 4
机架杆1 x 4
三通 x 6
机架杆2 x 5

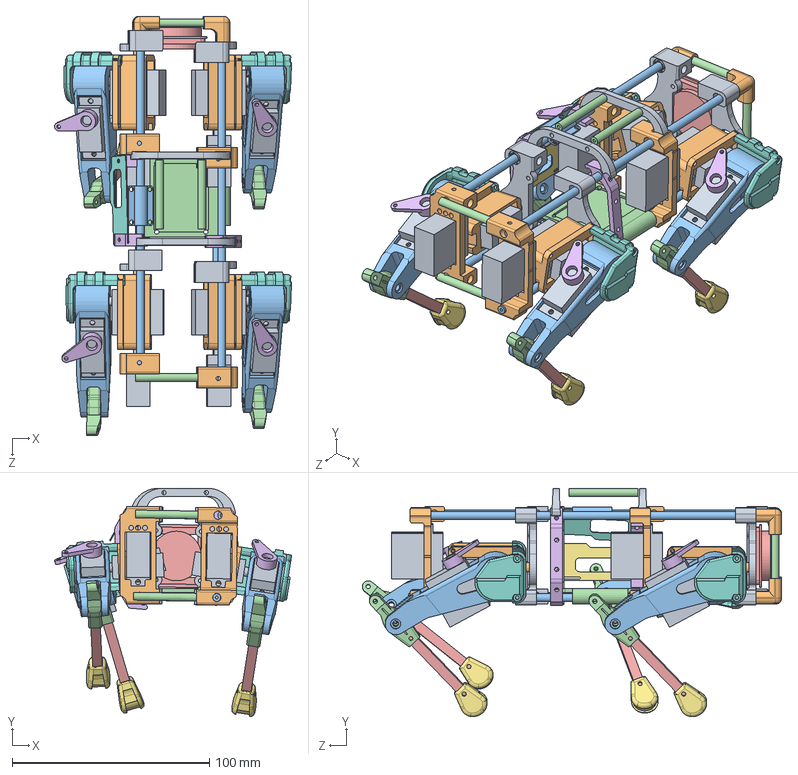
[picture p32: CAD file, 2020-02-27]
教程2-主机架设计/1.0 SW文件/moco-12直接固定.SLDASM
120.2 x 115.8 x 212.6 mm
9g舵机 x 12
大腿舵机固定 x 4
大腿_舵机 x 4
小腿连杆固定1 x 4
小腿杆 x 4
摇臂1 x 4
足底 x 4
大腿圆盘固定 x 4
跨固定2 x 4
跨舵机固定 x 4
机架杆1 x 4
机架杆2 x 9
风扇
侧支架 x 3
侧主板
侧主板顶
顶支架 x 2
三通 x 4
连杆固定
主控支撑

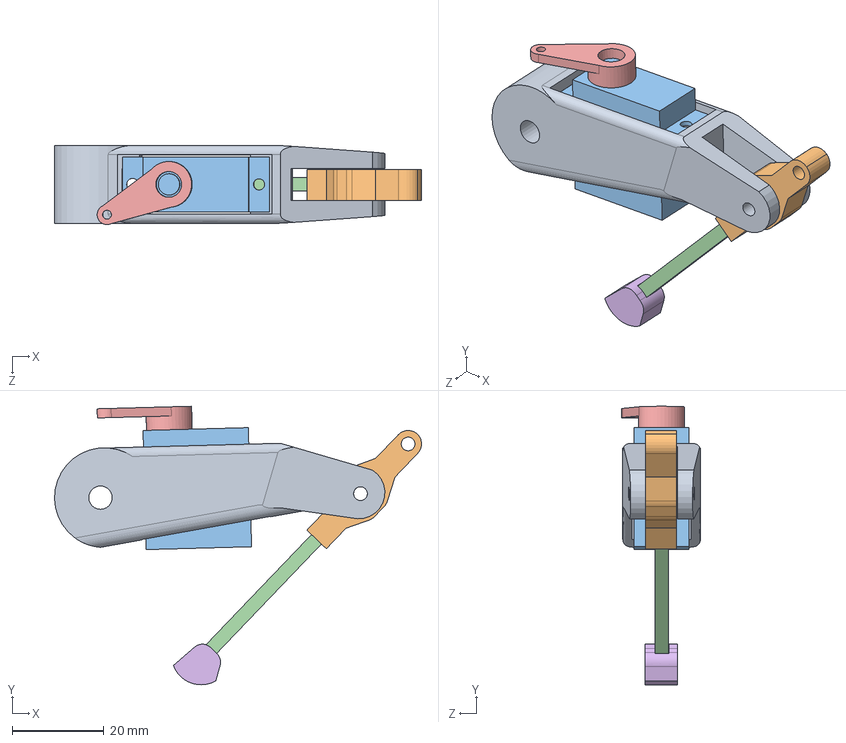
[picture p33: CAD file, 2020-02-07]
教程2-主机架设计/1.0 SW文件/大腿1.SLDASM
80.1 x 60.8 x 17.3 mm
大腿_舵机
小腿连杆固定1
9g舵机
小腿杆
摇臂1
足底

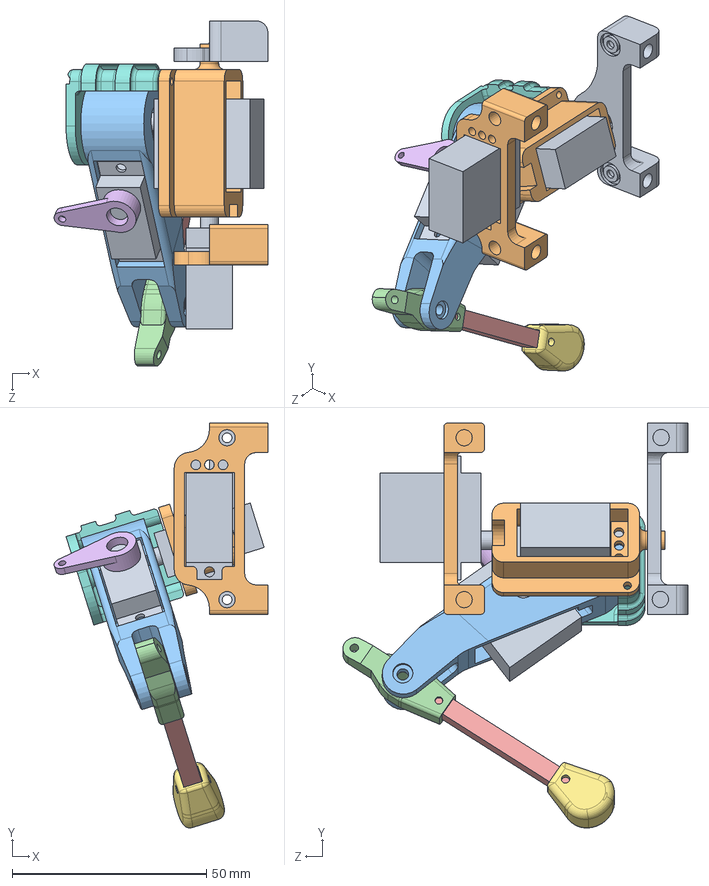
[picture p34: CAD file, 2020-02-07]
教程2-主机架设计/1.0 SW文件/单腿装配.SLDASM
55.1 x 104.3 x 88.9 mm
9g舵机 x 3
大腿舵机固定
大腿_舵机
小腿连杆固定1
小腿杆
摇臂1
足底
大腿圆盘固定
跨固定2
跨舵机固定

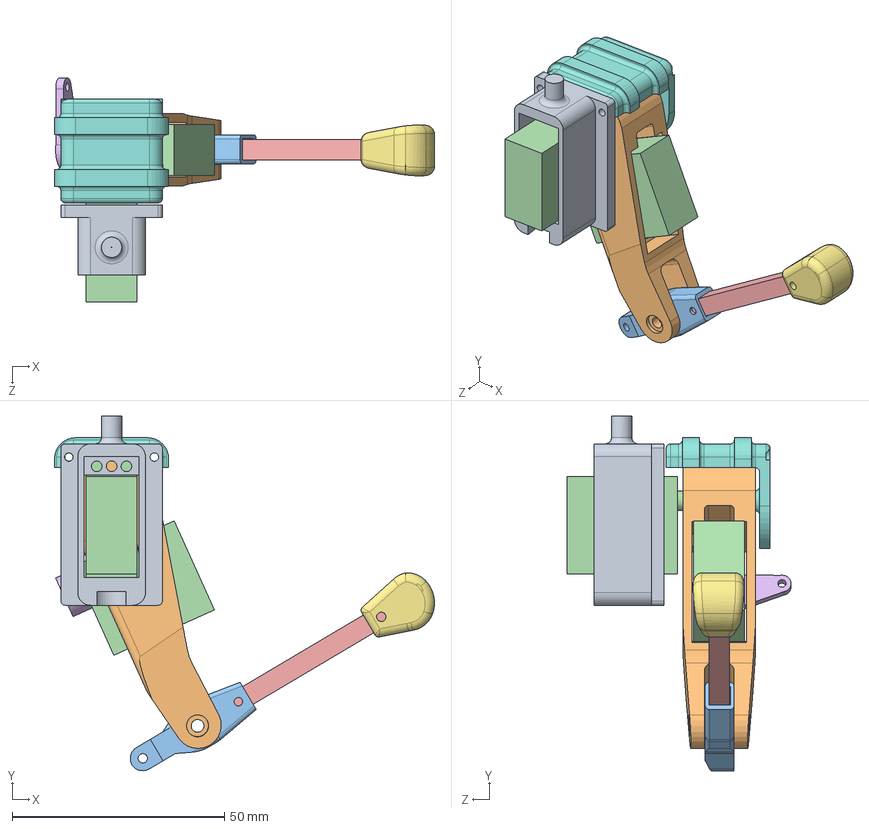
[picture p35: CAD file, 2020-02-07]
教程2-主机架设计/1.0 SW文件/大腿小腿装配.SLDASM
89.5 x 83.5 x 52.8 mm
大腿舵机固定
大腿_舵机
小腿连杆固定1
9g舵机 x 2
小腿杆
摇臂1
足底
大腿圆盘固定

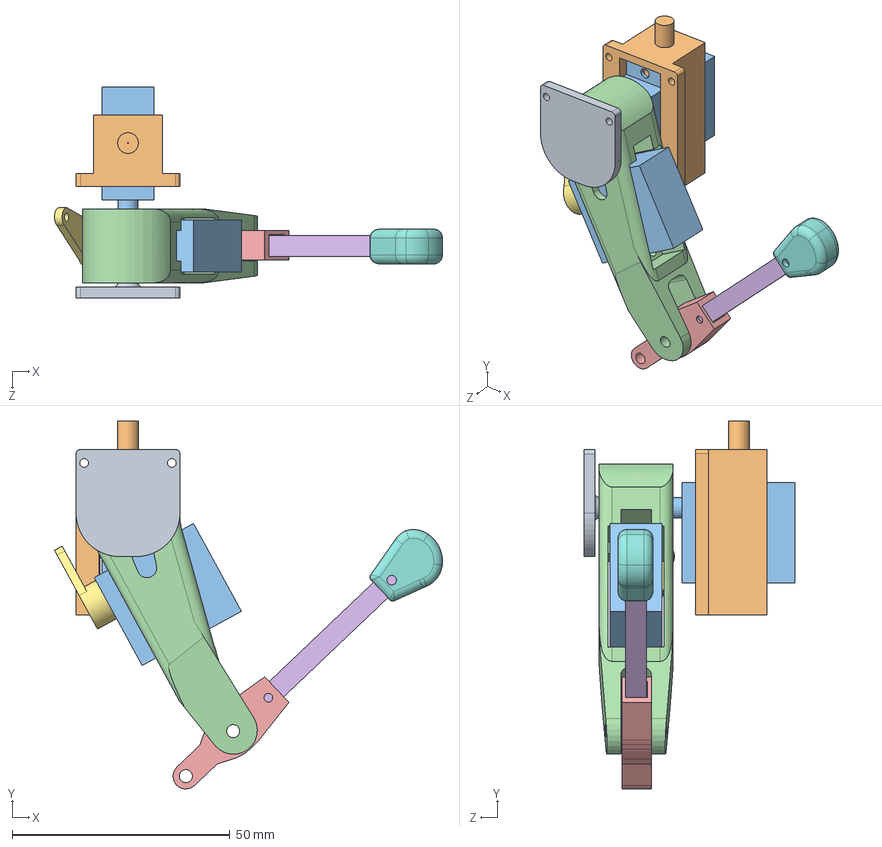
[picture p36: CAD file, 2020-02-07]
教程2-主机架设计/1.0 SW文件/大腿小腿装配j.SLDASM
89.2 x 84.5 x 48.5 mm
大腿圆盘固定
大腿舵机固定
9g舵机 x 2
大腿_舵机
小腿连杆固定1
小腿杆
摇臂1
足底

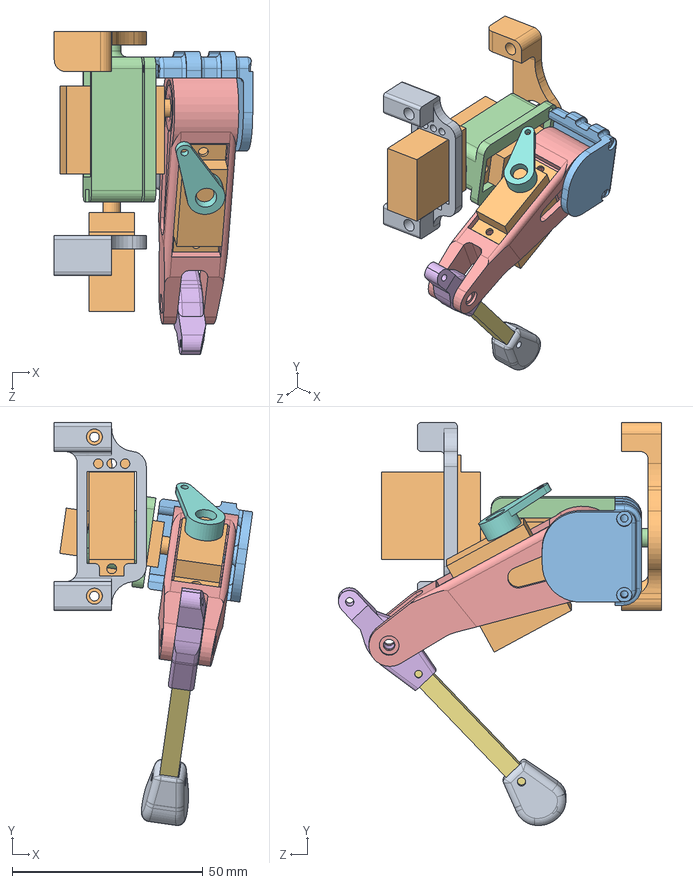
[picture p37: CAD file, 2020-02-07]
教程2-主机架设计/1.0 SW文件/单腿装配j.SLDASM
52.0 x 105.6 x 84.6 mm
跨舵机固定
9g舵机 x 3
大腿圆盘固定
大腿舵机固定
大腿_舵机
小腿连杆固定1
小腿杆
摇臂1
足底
跨固定2

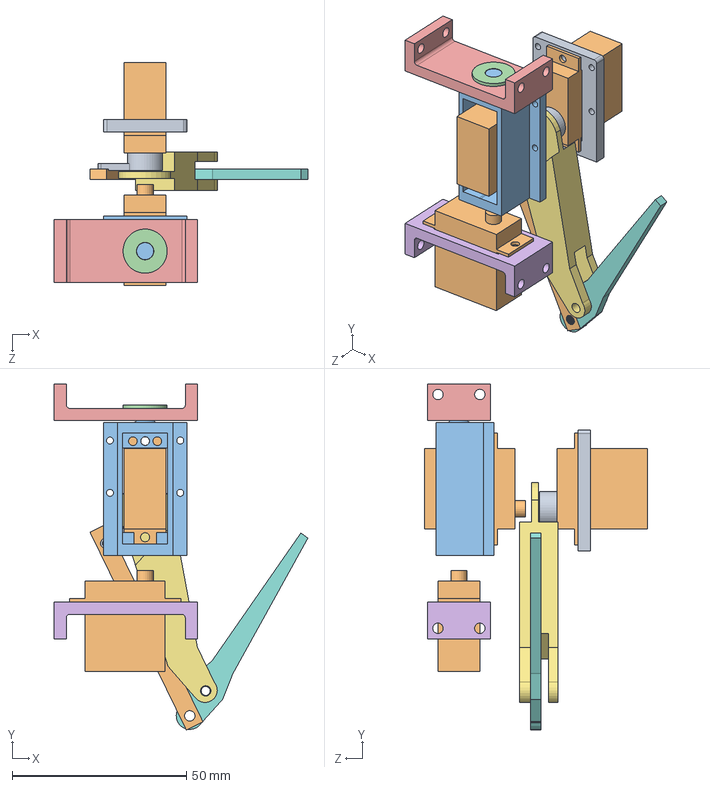
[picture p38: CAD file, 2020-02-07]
教程2-主机架设计/1.0 SW文件/跨关节1.SLDASM
72.8 x 99.2 x 64.0 mm
大腿1
9g舵机 x 3
大腿2
5 10 4 法兰
跨固定1
跨舵机固定
大腿
小腿
摇臂1
连杆

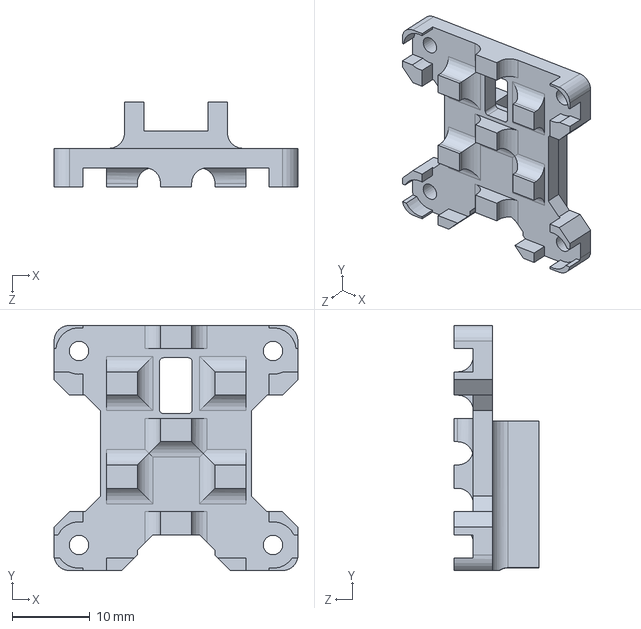
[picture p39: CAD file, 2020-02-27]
教程2-主机架设计/1.0 SW文件/后部供电.SLDPRT
31.4 x 31.6 x 11.0 mm

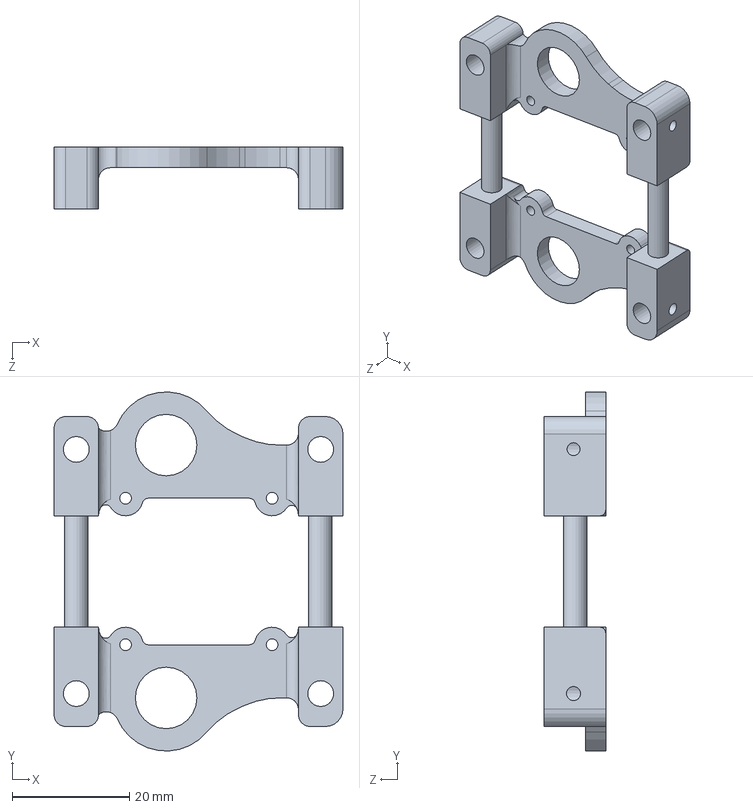
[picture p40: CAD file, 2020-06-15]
教程2-主机架设计/1.2 版本加工文件/主机架固定件（前后 2个）.SLDPRT
49.3 x 61.3 x 10.5 mm

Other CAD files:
教程2-主机架设计/1.2 版本加工文件/整机.SLDASM
教程2-主机架设计/moco-8 Test Verison/侧摆电机.SLDPRT
教程2-主机架设计/1.0 SW文件/开关支撑.SLDPRT
教程2-主机架设计/1.2 版本加工文件/小腿杆 4个.SLDPRT
教程2-主机架设计/1.0 SW文件/5 10 4 法兰.SLDPRT
教程2-主机架设计/1.0 SW文件/三通.SLDPRT
教程2-主机架设计/1.0 SW文件/三通1.SLDPRT
教程2-主机架设计/1.0 SW文件/主控支撑.SLDPRT
教程2-主机架设计/1.0 SW文件/侧主板.SLDPRT
教程2-主机架设计/1.0 SW文件/侧主板顶.SLDPRT
教程2-主机架设计/1.0 SW文件/侧支架.SLDPRT
教程2-主机架设计/1.0 SW文件/大腿_舵机.SLDPRT
教程2-主机架设计/1.0 SW文件/大腿_舵机保护.SLDPRT
教程2-主机架设计/1.0 SW文件/大腿圆盘固定.SLDPRT
教程2-主机架设计/1.0 SW文件/大腿圆盘固定1.SLDPRT
教程2-主机架设计/1.0 SW文件/大腿圆盘固定长.SLDPRT
教程2-主机架设计/1.0 SW文件/大腿舵机固定.SLDPRT
教程2-主机架设计/1.0 SW文件/小腿杆.SLDPRT
教程2-主机架设计/1.0 SW文件/小腿连杆固定1.SLDPRT
教程2-主机架设计/1.0 SW文件/摇臂1.SLDPRT
教程2-主机架设计/1.0 SW文件/机架杆1.SLDPRT
教程2-主机架设计/1.0 SW文件/机架杆2.SLDPRT
教程2-主机架设计/1.0 SW文件/电池仓.SLDPRT
教程2-主机架设计/1.0 SW文件/足底.SLDPRT
教程2-主机架设计/1.0 SW文件/跨固定1.SLDPRT
教程2-主机架设计/1.0 SW文件/跨固定2.SLDPRT
教程2-主机架设计/1.0 SW文件/跨固定2双.SLDPRT
教程2-主机架设计/1.0 SW文件/跨舵机固定.SLDPRT
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

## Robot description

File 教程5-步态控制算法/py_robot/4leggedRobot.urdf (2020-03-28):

<?xml version="1.0"?>
<robot name="materials">

  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

  <link name="base_link">
    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
    <inertial>
      <origin xyz="0.0000413575 0.00525148 -0.00174497"/>
      <mass value="1.843" />
      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
    </inertial>
    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
  </link>


#FRONT RIGHT
  <link name="coxa_FR">
    <inertial>
      <mass value="0.0827" />
      <origin xyz="0.0973055 -0.0661692 -0.00513185"/>
      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
    </inertial>
    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
  </link>

  <link name="femur_FR">
    <inertial>
      <mass value="0.1784" />
      <origin xyz="0.0950414 -0.0741722 -0.0449003"/>
      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
    </inertial>
    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
  </link>

  <link name="tibia_FR">
    <inertial>
      <mass value="0.0377" />
      <origin xyz="0.0944505 -0.07488 -0.16028"/>
      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
    </inertial>
    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
  </link>

  <link name="foot_FR">
    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
    <inertial>
      <mass value="0.0044" />
      <origin xyz="0.0895379 -0.0748802 -0.220739"/>
      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
    </inertial>
    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
  </link>
  
  <joint name="coxaF_FR" type="revolute">
    <axis xyz="1 0 0"/>
    <limit effort="1000.0" velocity="0.5"/>
    <parent link="base_link"/>
    <child link="coxa_FR"/>
    <origin xyz="0.095 -0.07 0"/>
  </joint>

  <joint name="femurF_FR" type="revolute">
    <axis xyz="0 1 0"/>
    <limit effort="1000.0" velocity="0.5"/>
    <parent link="coxa_FR"/>
    <child link="femur_FR"/>
    <origin xyz="0 -0.035 0"/>
  </joint>

  <joint name="tibiaF_FR" type="revolute">
    <axis xyz="0 1 0"/>
    <limit effort="1000.0" velocity="0.5"/>
    <parent link="femur_FR"/>
    <child link="tibia_FR"/>
    <origin xyz="0 0 -0.11"/>
  </joint>

  <joint name="footF_FR" type="fixed">
    <parent link="tibia_FR"/>
    <child link="foot_FR"/>
    <origin xyz="0 0 -0.11"/>
  </joint>




#FRONT LEFT



  <link name="coxa_FL">
    <inertial>
      <mass value="0.0827" />
      <origin xyz="0.0973055 0.0764089 -0.00513185"/>
      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
    </inertial>
    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
  </link>

  <link name="femur_FL">
    <inertial>
      <mass value="0.1784" />
      <origin xyz="0.0950414 0.0844119 -0.0449003"/>  
      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
    </inertial>
    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
  </link>

  <link name="tibia_FL">
   <inertial>
      <mass value="0.0377" />
      <origin xyz="0.0944494 0.0851198 -0.160284"/>
      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
    </inertial>
    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
  </link>

  <link name="foot_FL">
    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
    <inertial>
      <mass value="0.00044" />
      <origin xyz="0.0895379 0.0851198 -0.220739"/>
      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
    </inertial>
    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
  </link>
  
  <joint name="coxaF_FL" type="revolute">
    <axis xyz="1 0 0"/>
    <limit effort="1000.0" velocity="0.5"/>
    <parent link="base_link"/>
    <child link="coxa_FL"/>
    <origin xyz="0.1 0.07 0"/>
  </joint>

  <joint name="femurF_FL" type="revolute">
    <axis xyz="0 1 0"/>
    <limit effort="1000.0" velocity="0.5"/>
    <parent link="coxa_FL"/>
    <child link="femur_FL"/>
    <origin xyz="0 0.035 0"/>
  </joint>

  <joint name="tibiaF_FL" type="revolute">
    <axis xyz="0 1 0"/>
    <limit effort="1000.0" velocity="0.5"/>
    <parent link="femur_FL"/>
    <child link="tibia_FL"/>
    <origin xyz="0 0 -0.11"/>
  </joint>

  <joint name="footF_FL" type="fixed">
    <parent link="tibia_FL"/>
    <child link="foot_FL"/>
    <origin xyz="0 0 -0.11"/>
  </joint>







#BACK RIGHT






  <link name="coxa_BR">
    <inertial>
      <mass value="0.178" />
      <origin xyz="-0.0769834 -0.0607364 -0.00509226"/>
      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
    </inertial>
    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
  </link>

  <link name="femur_BR">
    <inertial>
      <mass value="0.1784" />
      <origin xyz="-0.0949586 -0.0741722 -0.0449003"/>
      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
    </inertial>
    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
  </link>

  <link name="tibia_BR">
    <inertial>
      <mass value="0.039" />
      <origin xyz="-0.095328 -0.0748802 -0.159807"/>
      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
    </inertial>
    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
  </link>

  <link name="foot_BR">
    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
    <inertial>
      <mass value="0.0044" />
      <origin xyz="-0.100629 -0.0748802 -0.220419"/>
      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
    </inertial>
    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
  </link>
  
  <joint name="coxaF_BR" type="revolute">
    <axis xyz="1 0 0"/>
    <limit effort="1000.0" velocity="0.5"/>
    <parent link="base_link"/>
    <child link="coxa_BR"/>
    <origin xyz="-0.1 -0.07 0"/>
  </joint>

  <joint name="femurF_BR" type="revolute">
    <axis xyz="0 1 0"/>
    <limit effort="1000.0" velocity="0.5"/>
    <parent link="coxa_BR"/>
    <child link="femur_BR"/>
    <origin xyz="0 -0.035 0"/>
  </joint>

  <joint name="tibiaF_BR" type="revolute">
    <axis xyz="0 1 0"/>
    <limit effort="1000.0" velocity="0.5"/>
    <parent link="femur_BR"/>
    <child link="tibia_BR"/>
    <origin xyz="0 0 -0.11"/>
  </joint>

  <joint name="footF_BR" type="fixed">
    <parent link="tibia_BR"/>
    <child link="foot_BR"/>
    <origin xyz="0 0 -0.11"/>
  </joint>



#BACK LEFT




  <link name="coxa_BL">
    <inertial>
      <mass value="0.178" />
      <origin xyz="-0.0769834 0.0709761 -0.00509226"/>
      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
    </inertial>
    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
  </link>

  <link name="femur_BL">
    <inertial>
      <mass value="0.1784" />
      <origin xyz="-0.0949586 0.0844119 -0.0449003"/>
      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
    </inertial>
    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
  </link>

  <link name="tibia_BL">
    <inertial>
      <mass value="0.039" />
      <origin xyz="-0.0953282 0.0851197 -0.159807"/>
      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
    </inertial>
    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
  </link>

  <link name="foot_BL">
    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
    <inertial>
      <mass value="0.0044" />
      <origin xyz="-0.100629 0.0851198 -0.220419"/>
      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
    </inertial>
    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
  </link>
  
  <joint name="coxaF_BL" type="revolute">
    <axis xyz="1 0 0"/>
    <limit effort="1000.0" velocity="0.5"/>
    <parent link="base_link"/>
    <child link="coxa_BL"/>
    <origin xyz="-0.1 0.07 0"/>
  </joint>

  <joint name="femurF_BL" type="revolute">
    <axis xyz="0 1 0"/>
    <limit effort="1000.0" velocity="0.5"/>
    <parent link="coxa_BL"/>
    <child link="femur_BL"/>
    <origin xyz="0 0.035 0"/>
  </joint>

  <joint name="tibiaF_BL" type="revolute">
    <axis xyz="0 1 0"/>
    <limit effort="1000.0" velocity="0.5"/>
    <parent link="femur_BL"/>
    <child link="tibia_BL"/>
    <origin xyz="0 0 -0.11"/>
  </joint>

  <joint name="footF_BL" type="fixed">
    <parent link="tibia_BL"/>
    <child link="foot_BL"/>
    <origin xyz="0 0 -0.11"/>
  </joint>
</robot>

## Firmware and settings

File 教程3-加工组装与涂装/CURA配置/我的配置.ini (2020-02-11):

[profile]
layer_height = 0.2
wall_thickness = 1.2
retraction_enable = True
solid_layer_thickness = 0.6
fill_density = 25
print_speed = 50
print_temperature = 200
print_temperature2 = 0
print_temperature3 = 0
print_temperature4 = 0
print_temperature5 = 0
print_bed_temperature = 60
support = Touching buildplate
platform_adhesion = Brim
support_dual_extrusion = Both
wipe_tower = False
wipe_tower_volume = 15
ooze_shield = False
filament_diameter = 1.75
filament_diameter2 = 0
filament_diameter3 = 0
filament_diameter4 = 0
filament_diameter5 = 0
filament_flow = 100.0
nozzle_size = 0.4
retraction_speed = 60
retraction_amount = 5
retraction_dual_amount = 16.5
retraction_min_travel = 1.5
retraction_combing = All
retraction_minimal_extrusion = 0.02
retraction_hop = 0.0
bottom_thickness = 0.2
layer0_width_factor = 100
object_sink = 0.0
overlap_dual = 0.15
travel_speed = 20
bottom_layer_speed = 20
infill_speed = 0.0
solidarea_speed = 30
inset0_speed = 30
insetx_speed = 40
cool_min_layer_time = 5
fan_enabled = True
skirt_line_count = 1
skirt_gap = 3.0
skirt_minimal_length = 150.0
fan_full_height = 0.5
fan_speed = 100
fan_speed_max = 100
cool_min_feedrate = 10
cool_head_lift = False
solid_top = True
solid_bottom = True
fill_overlap = 15
perimeter_before_infill = False
support_type = Lines
support_angle = 60
support_fill_rate = 10
support_xy_distance = 0.7
support_z_distance = 0.15
spiralize = False
simple_mode = False
brim_line_count = 20
raft_margin = 5.0
raft_line_spacing = 1.5
raft_base_thickness = 0.3
raft_base_linewidth = 1.0
raft_interface_thickness = 0.27
raft_interface_linewidth = 0.4
raft_airgap_all = 0.0
raft_airgap = 0.22
raft_surface_layers = 2
raft_surface_thickness = 0.27
raft_surface_linewidth = 0.4
fix_horrible_union_all_type_a = True
fix_horrible_union_all_type_b = False
fix_horrible_use_open_bits = False
fix_horrible_extensive_stitching = False
plugin_config = 
object_center_x = -1
object_center_y = -1

[alterations]
start.gcode = ;Sliced at: {day} {date} {time}
	;Basic settings: Layer height: {layer_height} Walls: {wall_thickness} Fill: {fill_density}
	;Print time: {print_time}
	;Filament used: {filament_amount}m {filament_weight}g
	;Filament cost: {filament_cost}
	;M190 S{print_bed_temperature} ;Uncomment to add your own bed temperature line
	;M109 S{print_temperature} ;Uncomment to add your own temperature line
	G21        ;metric values
	G90        ;absolute positioning
	M82        ;set extruder to absolute mode
	M107       ;start with the fan off
	G28 X0 Y0  ;move X/Y to min endstops
	G28 Z0     ;move Z to min endstops
	G1 Z15.0 F{travel_speed} ;move the platform down 15mm
	G92 E0                  ;zero the extruded length
	G1 F200 E3              ;extrude 3mm of feed stock
	G92 E0                  ;zero the extruded length again
	G1 F{travel_speed}
	;Put printing message on LCD screen
	M117 Printing...
end.gcode = ;End GCode
	M104 S0                     ;extruder heater off
	M140 S0                     ;heated bed heater off (if you have it)
	G91                                    ;relative positioning
	G1 E-1 F300                            ;retract the filament a bit before lifting the nozzle, to release some of the pressure
	G1 Z+0.5 E-5 X-20 Y-20 F{travel_speed} ;move Z up a bit and retract filament even more
	G28 X0 Y0                              ;move X/Y to min endstops, so the head is out of the way
	M84                         ;steppers off
	G90                         ;absolute positioning
	;{profile_string}
start2.gcode = ;Sliced at: {day} {date} {time}
	;Basic settings: Layer height: {layer_height} Walls: {wall_thickness} Fill: {fill_density}
	;Print time: {print_time}
	;Filament used: {filament_amount}m {filament_weight}g
	;Filament cost: {filament_cost}
	;M190 S{print_bed_temperature} ;Uncomment to add your own bed temperature line
	;M104 S{print_temperature} ;Uncomment to add your own temperature line
	;M109 T1 S{print_temperature2} ;Uncomment to add your own temperature line
	;M109 T0 S{print_temperature} ;Uncomment to add your own temperature line
	G21        ;metric values
	G90        ;absolute positioning
	M107       ;start with the fan off
	G28 X0 Y0  ;move X/Y to min endstops
	G28 Z0     ;move Z to min endstops
	G1 Z15.0 F{travel_speed} ;move the platform down 15mm
	T1                      ;Switch to the 2nd extruder
	G92 E0                  ;zero the extruded length
	G1 F200 E10             ;extrude 10mm of feed stock
	G92 E0                  ;zero the extruded length again
	G1 F200 E-{retraction_dual_amount}
	T0                      ;Switch to the first extruder
	G92 E0                  ;zero the extruded length
	G1 F200 E10             ;extrude 10mm of feed stock
	G92 E0                  ;zero the extruded length again
	G1 F{travel_speed}
	;Put printing message on LCD screen
	M117 Printing...
end2.gcode = ;End GCode
	M104 T0 S0                     ;extruder heater off
	M104 T1 S0                     ;extruder heater off
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

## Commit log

2020-02-07 更新教程2
    [5 10 4 法兰.SLDPRT, 9g舵机.SLDPRT, 三通.SLDPRT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]
2020-02-27 更新BOM表
    [模型主控V1.xls]
2020-02-27 update模型
    [moco-12.SLDASM, moco-12直接固定.SLDASM, 主控支撑.SLDPRT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]
2020-03-28 更新第5章
    [4leggedRobot.urdf]
2020-06-15 更新 1.0内测版本
    [5 10 4 法兰.SLDPRT, 9g舵机.SLDPRT, EXPLORER.SCHLIB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]
2020-06-19 更新1.1估计
